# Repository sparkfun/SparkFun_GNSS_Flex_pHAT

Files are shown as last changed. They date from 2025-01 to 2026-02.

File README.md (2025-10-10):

SparkFun GNSS Flex pHAT
========================================

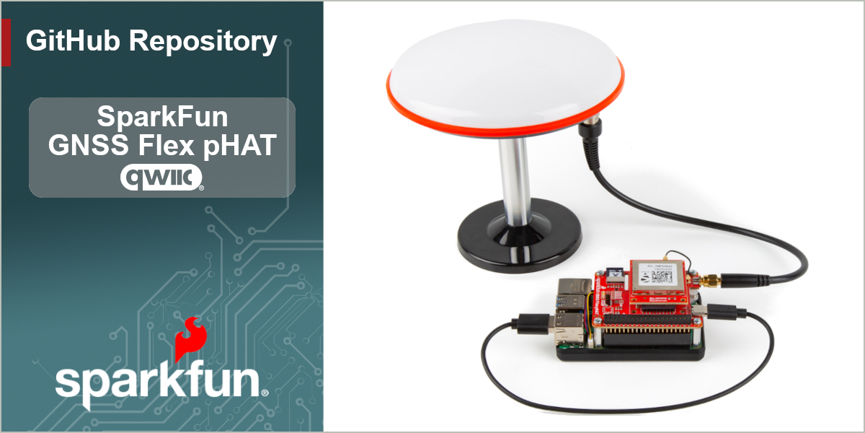
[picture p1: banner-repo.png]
SparkFun GNSS Flex pHAT


[*SparkFun GNSS Flex pHAT (GPS-28137)*](https://www.sparkfun.com/sparkfun-gnss-flex-phat.html)

The [SparkFun GNSS Flex pHAT](https://www.sparkfun.com/sparkfun-gnss-flex-phat.html) is a Raspberry Pi pHAT that functions as a *carrier board* for our SparkPNT GNSS Flex modules. With pre-soldered headers, no soldering is required to stack the pHAT on the headers of a Raspberry Pi, NVIDIA Jetson Nano, Google Coral, or other single-board computer with a similar 40-pin header.

The GNSS Flex pHAT also comes populated with two sets of 2x10 pin, 2mm pitch male headers for attaching a GNSS Flex module. With these headers, the GNSS Flex system is designed to be modular so that boards are pin-compatible for upgrades and can be easily swapped for repairs. Depending on the capabilities of the GNSS Flex module that is connected, these pins will breakout the USB, UART (x4), I<sup>2</sup>C, and SD card interfaces for the GNSS receiver along with any PPS or event signals, using a standardized pin out.

> [!NOTE]
> By default, we use the Raspberry Pi's primary serial bus *(i.e. **TX:** `GPIO14`/Pin `8`; **RX:** `GPIO15`/Pin `9`)* to communicate with the GNSS receiver of the SparkPNT GNSS Flex module. However, users can also utilize any of the other interfaces.

> [!IMPORTANT]
> Depending on the GNSS Flex module, this product will likely require an external antenna:
>
> - Be sure to check out the hookup guide for more information on the GNSS Flex module.
> - Users can also find [GNSS Antennas](https://www.sparkfun.com/gnss/gnss-antennas.html) in our catalog.
>
> Users will have two options for connecting an external GNSS antenna to their GNSS receiver.
>
> - The GNSS Flex modules will usually come with a U.FL connector for external antenna.
> - For a sturdier connection, an SMA connector is available on the SparkFun GNSS Flex pHAT that is bridged to an U.FL connector. Users simply need to jumper the U.FL connectors on both the SparkPNT GNSS Flex module and SparkFun GNSS Flex pHAT with a short U.FL cable.

> [!TIP]
> The SparkFun GNSS Flex pHAT has been tested and verified on the following platforms:
> - [Raspberry Pi](https://www.sparkfun.com/development-boards/single-board-computers/raspberry-pi/raspberry-pi-boards.html): 3B, 3B+, 3A+, Zero 2W, 4B, 5B
> - [NVidia Jetson Orin Nano](https://www.sparkfun.com/nvidia-jetson-orin-nano-developer-kit.html)

Documentation
--------------
- **[Hookup Guide (mkdocs)](http://docs.sparkfun.com/SparkFun_GNSS_Flex_System/)** - A hookup guide for the entire ecosystem of SparkFun GNSS Flex carrier boards and SparkPNT GNSS Flex modules, hosted by GitHub pages.<br>
   

Repository Contents
-------------------
- **[/docs](/docs/)** - Online documentation files
  - [/assets](/docs/assets/) - Assets files
    - [/3d_model](/docs/assets/3d_model/) - Files for the 3D models
      - [/3D CAD Model](/docs/assets/3d_model/cad_model.step) (.step)
    - [/board_files](/docs/assets/board_files/) - Files for the product design
      - [KiCad Design Files](/docs/assets/board_files/kicad_files.zip) (.zip)
      - [Schematic](/docs/assets/board_files/schematic.pdf) (.pdf)
      - [Dimensions](/docs/assets/board_files/dimensions.pdf) (.pdf)
    - [/component_documentation](/docs/assets/component_documentation/) - Datasheets for hardware components
    - [/img/hookup_guide/](/docs/assets/img/hookup_guide/) - Images for hookup guide documentation
- **[/Hardware](/Hardware/)** - Hardware design files (.brd, .sch)
  - **[/Production](/Production/)** - Production files

Product Variants
----------------
GNSS Flex *Carrier* Boards:
- [GPS-28962](https://www.sparkfun.com/sparkfun-gnss-flex-breakout.html) - GNSS Flex Breakout
- [GPS-28137](https://www.sparkfun.com/sparkfun-gnss-flex-phat.html) - GNSS Flex pHAT *(only)*

- GNSS Flex pHAT Kits:
  - pHAT + GNSS Module *(only)*:
    - [GPS-28766](https://www.sparkfun.com/sparkfun-gnss-flex-phat-mosaic-x5.html) - w/ the Septentrio mosaic-X5 GNSS Flex module
    - [GPS-28929](https://www.sparkfun.com/sparkfun-gnss-flex-phat-lg290p.html) - w/ the Quectel LG290P GNSS Flex module
    - [GPS-29491](https://www.sparkfun.com/sparkfun-gnss-flex-phat-dan-f10n.html) - w/ the u-blox DAN-F10N GNSS Flex module
    - [GPS-29887](https://www.sparkfun.com/sparkfun-gnss-flex-phat-zed-x20p.html) - w/ the u-blox ZED-X20P GNSS Flex module
    - [GPS-29890](https://www.sparkfun.com/sparkfun-gnss-flex-phat-lg580p.html) - w/ the Quectel LG580P GNSS Flex module
  - pHAT + GNSS Module w/ IMU:
    - [GPS-29891](https://www.sparkfun.com/sparkfun-gnss-flex-phat-lg290p-im19-imu.html) - w/ the Quectel LG290P GNSS Flex module + IM19 IMU
    - [GPS-29888](https://www.sparkfun.com/sparkfun-gnss-flex-phat-zed-x20p-im19-imu.html) - w/ the u-blox ZED-X20P GNSS Flex module + IM19 IMU

Version History
---------------
- [v01](https://github.com/sparkfun/SparkFun_GNSS_Flex_pHAT/releases/tag/v01) - Initial Release
- [v02](https://github.com/sparkfun/SparkFun_GNSS_Flex_pHAT/releases/tag/v02) - Adds DAN-F10N GNSS Flex module
- [v03](https://github.com/sparkfun/SparkFun_GNSS_Flex_pHAT/releases/tag/v03) - Adds LG290P and ZED-X20P GNSS Flex modules w/ optional IM19 IMU
- [v04](https://github.com/sparkfun/SparkFun_GNSS_Flex_pHAT/releases/tag/v04) - Update docs and link GNSS Flex breakout board
- [v10](https://github.com/sparkfun/SparkFun_GNSS_Flex_pHAT/releases/tag/v10) - Refactored the 3D model for new color adjustment script and linked the LG580P GNSS Flex module

License Information
-------------------

This product is ***open source***!

Please review the [`LICENSE.md`](./LICENSE.md) file for license information.

If you have any questions or concerns about licensing, please contact technical support on our [SparkFun forums](https://forum.sparkfun.com/viewforum.php?f=152).

Distributed as-is; no warranty is given.

- Your friends at SparkFun.

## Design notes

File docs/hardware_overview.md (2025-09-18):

<article style="text-align: center;" markdown>
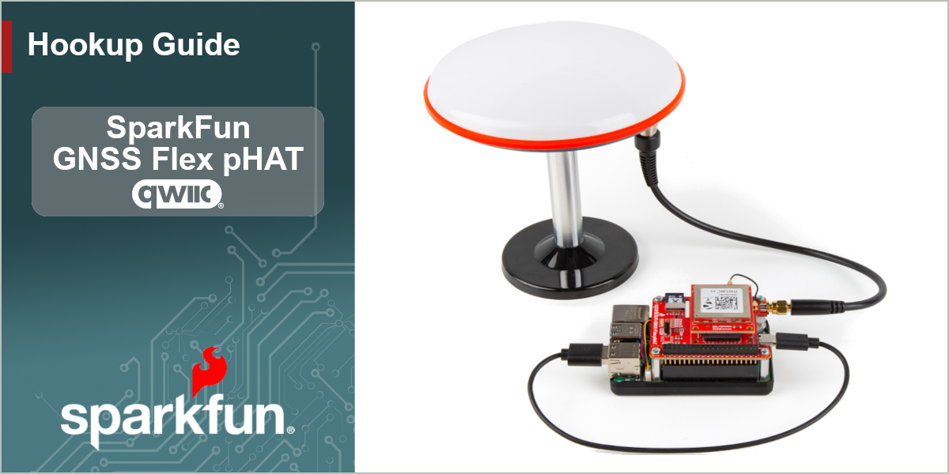
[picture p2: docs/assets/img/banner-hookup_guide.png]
Banner

</article>

!!! info "pHAT (not HAT+)"
	This is product does not completely meet Raspberry Pi's HAT+ specification.

	- An identification EEPROM is not populated on the board; however, we do provide a footprint for future use.
	- Without an ID EEPROM, a Raspberry Pi cannot automatically identify this board. Therefore, users will need to manually [install any software](software_overview.md) and provide configurations for the [hardware connections](#40-pin-gpio-header).

## Introduction

<div class="grid cards desc" markdown>

-   <a href="https://www.sparkfun.com/sparkfun-gnss-flex-phat.html">
	**SparkFun GNSS Flex pHAT**<br>
	**SKU:** GPS-28137

	---

	<figure markdown>
	Product Thumbnail
	</figure></a>

	<article style="text-align: center;" markdown>
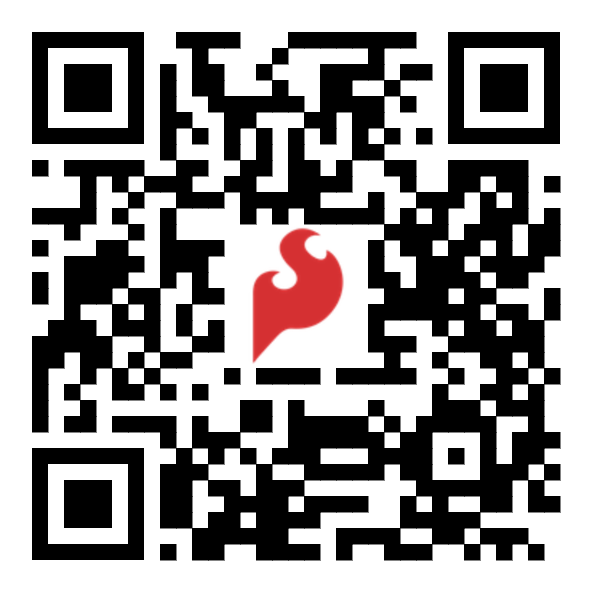
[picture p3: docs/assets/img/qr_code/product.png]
QR code to product page
	
	[Purchase from SparkFun :fontawesome-solid-cart-plus:{ .heart }](https://www.sparkfun.com/sparkfun-gnss-flex-phat.html){ .md-button .md-button--primary }
	</article>

-	The SparkFun GNSS Flex pHAT is a Raspberry Pi pHAT that functions as a [*carrier board*](../carriers.md) for our [SparkPNT GNSS Flex modules](../modules.md). With pre-soldered headers, no soldering is required to stack the pHAT on the headers of a Raspberry Pi, NVIDIA Jetson Nano, Google Coral, or other single-board computer with a similar 40-pin header.

	The GNSS Flex pHAT also comes populated with two sets of 2x10 pin, 2mm pitch male headers for attaching a GNSS Flex module. With these headers, the GNSS Flex system is designed to be modular so that boards are pin-compatible for upgrades and can be easily swapped for repairs. Depending on the capabilities of the GNSS Flex module that is connected, these pins will breakout the USB, UART (x4), I^2^C, and SD card interfaces for the GNSS receiver along with any PPS or event signals, using a standardized pin out.

</div>

## Design Files

<!-- Import the component -->
<script type="module" src="https://ajax.googleapis.com/ajax/libs/model-viewer/3.5.0/model-viewer.min.js"></script>

<div class="grid cards desc" markdown>

-   :kicad-primary:{ .enlarge-logo } **Design Files**

	---

	- :fontawesome-solid-file-pdf: [Schematic](./assets/board_files/schematic.pdf)
	- :material-folder-zip: [KiCad Files](./assets/board_files/kicad_files.zip)
	- :material-rotate-3d: [STEP File](./assets/3d_model/cad_model.step)
	- :fontawesome-solid-file-pdf: [Board Dimensions](./assets/board_files/dimensions.pdf):

	<br>

	**Hardware Included w/ Kit**

	---

	- x1 - [SparkPNT GNSS Flex Module](../modules.md)
	- x1 - [Tall GPIO Female Headers - 2x20 Pin](https://www.sparkfun.com/tall-gpio-female-headers-2x20-pin.html)
	- x1 - [50mm U.FL to U.FL Cable](https://www.sparkfun.com/u-fl-to-u-fl-mini-coax-cable-50mm.html)
	- x4 - Aluminum Hex Standoff
		- Thread: M2.5-0.45; Length: 16mm
	- x8 - Phillips Machine Screw
		- Thread: M2.5-0.45x8mm

-   <!-- Boxes in tabs -->

	=== "3D Model"
		<article style="text-align: center;" markdown>
		<model-viewer src="../assets/3d_model/web_model.glb" camera-controls poster="../assets/3d_model/poster.png" tone-mapping="neutral" shadow-intensity="2" shadow-softness="0.2" camera-orbit="0deg 75deg 0.1623m" field-of-view="25.11deg" style="width: 100%; height: 450px;">
		</model-viewer>
		</article>

		???+ tip "Manipulate 3D Model"
			<article style="text-align: center;" markdown>

			| Controls       | Mouse                    | Touchscreen    |
			| :------------- | :----------------------: | :------------: |
			| Zoom           | Scroll Wheel             | 2-Finger Pinch |
			| Rotate         | ++"Left-Click"++ & Drag  | 1-Finger Drag  |
			| Move/Translate | ++"Right-Click"++ & Drag | 2-Finger Drag  |

			</article>

	=== "Dimensions"
		<article style="text-align: center;" markdown>
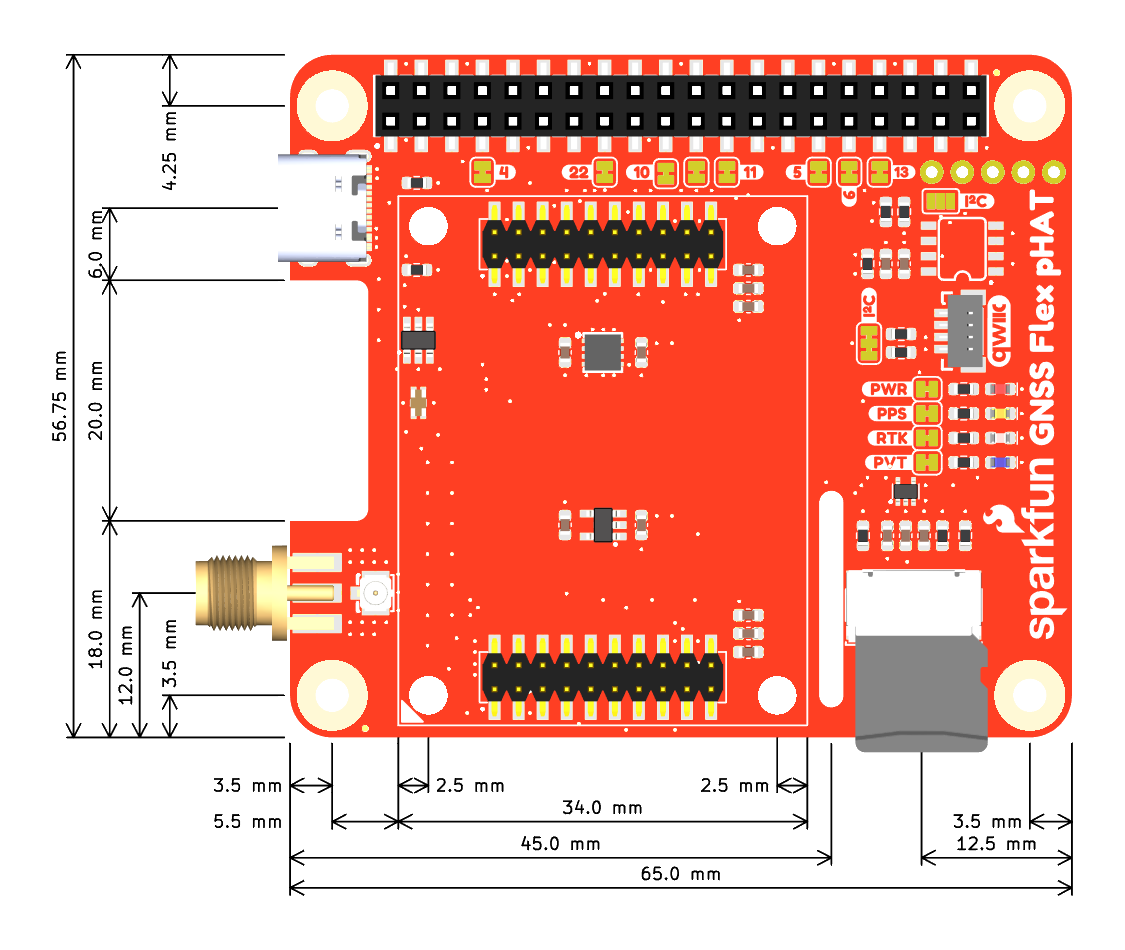
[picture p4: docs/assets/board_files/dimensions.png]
Board Dimensions
		
		<figcaption markdown>Dimensions of the GNSS Flex pHAT.</figcaption>
		</article>

		???+ tip "Need more measurements?"
			For more information about the board's dimensions, users can download the [KiCad files](./assets/board_files/kicad_files.zip) for this board. These files can be opened in KiCad and additional measurements can be made with the measuring tool.

			!!! info ":octicons-download-16:{ .heart } KiCad - Free Download!"
				KiCad is free, open-source [CAD]("computer-aided design") program for electronics. Click on the button below to download their software. *(\*Users can find out more information about KiCad from their [website](https://www.kicad.org/).)*

				<article style="text-align: center;" markdown>
				[Download :kicad-primary:{ .enlarge-logo }](https://www.kicad.org/download/ "Go to downloads page"){ .md-button .md-button--primary }
				</article>

			???+ info ":straight_ruler: Measuring Tool"
				This video demonstrates how to utilize the dimensions tool in KiCad, to include additional measurements:

				<article class="video-500px" style="text-align: center; margin: auto;" markdown>
				<iframe src="https://www.youtube.com/embed/-eXuD8pkCYw" title="KiCad Dimension Tool" frameborder="0" allow="accelerometer; autoplay; clipboard-write; encrypted-media; gyroscope; picture-in-picture" allowfullscreen></iframe>
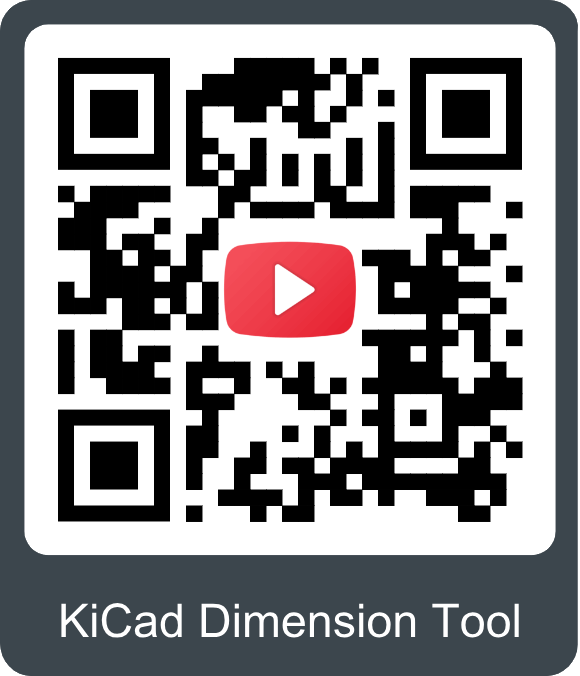
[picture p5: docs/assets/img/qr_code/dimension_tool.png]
QR code to play video
				
				</article>

</div>

## Board Layout
The GNSS Flex system is designed around two 2x10-pin, 2mm pitch headers used mate the two types of boards. A standardized pin layout, keeps the ecosystem pin-compatible for upgrades and allows board to be easily swapped for repairs. Depending on the capabilities of the GNSS receiver, these pins will breakout the USB, UART (x4), I^2^C, and SD card interfaces along with any PPS or event signals of the GNSS receiver.

<figure markdown>
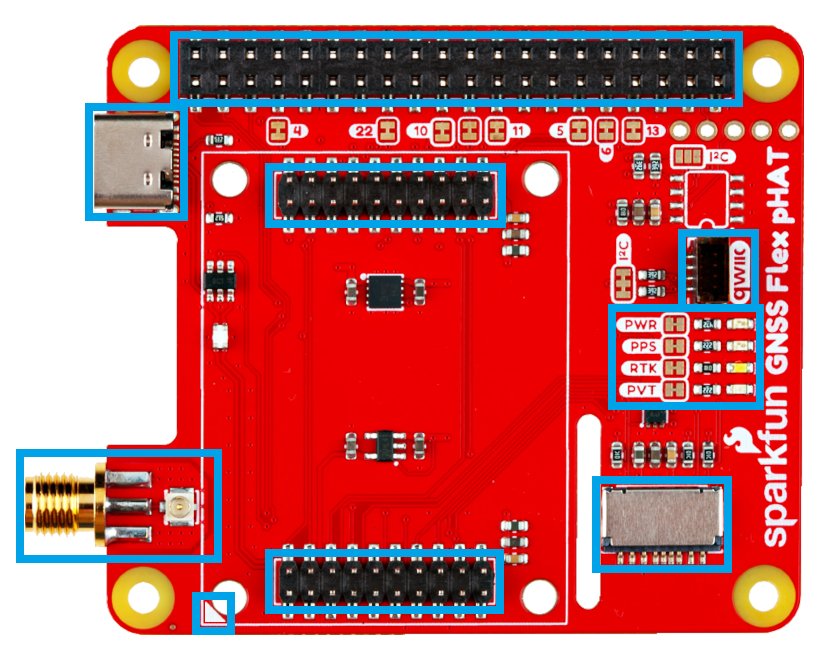
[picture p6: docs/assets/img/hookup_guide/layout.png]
Board Layout

<figcaption markdown>Layout of the major components of the GNSS Flex pHAT.</figcaption>
</figure>

The GNSS Flex pHAT has the following features:

1. **40-pin GPIO Header**
:	The 2x20 pin, 0.1" pitch female header for stacking the pHAT on top the Raspberry Pi's 40-pin GPIO header.
1. **GNSS Flex Headers**
:	Two sets of 2x10 pin, 2mm pitch female headers for connecting a GNSS Flex module.
1. **Alignment Indicator**
: Used to indicate the board alignment of a GNSS Flex module.
1. **Antenna Bridge**
:	U.FL and SMA connectors for attaching an external GNSS antenna.
1. **Status LEDs**
: Four status indication LEDs for the pHAT and attached GNSS Flex module.
1. **USB-C Connector**
:	A USB connector that breaks out the USB interface of an attached GNSS Flex module.
1. **SD Card Slot**
: Depending on the capabilities of the GNSS Flex module, a &micro;SD card slot for data logging.
1. **Qwiic Connector**
: A Qwiic connector for attaching peripheral devices to the I^2^C bus.

## Antenna Bridge
The SMA connector provides users with a more robust interface for attaching an external GNSS antenna. With the U.FL and SMA connectors bridged together and their ground plane isolated from the rest of the board, this allows users to pass the antenna connection from the GNSS Flex module to the GNSS Flex pHAT.

<figure markdown>
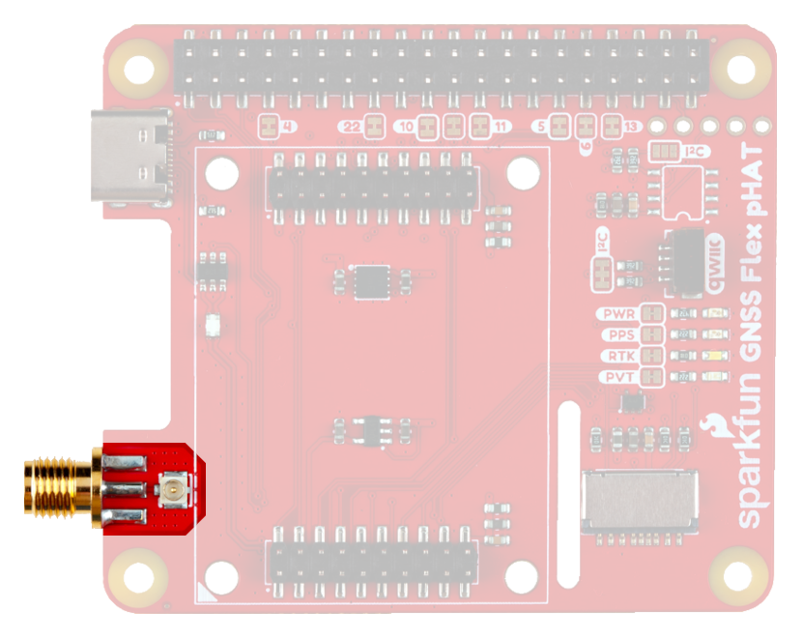
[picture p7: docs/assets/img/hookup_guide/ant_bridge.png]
Antenna bridge

<figcaption markdown>An SMA antenna bridge on the GNSS Flex pHAT, which provides a more robust connection.</figcaption>
</figure>

## 40-pin GPIO Header
In its simplest form, the SparkFun GNSS Flex pHAT sits atop a Raspberry Pi interfacing with its 40-pin header.

<figure markdown>
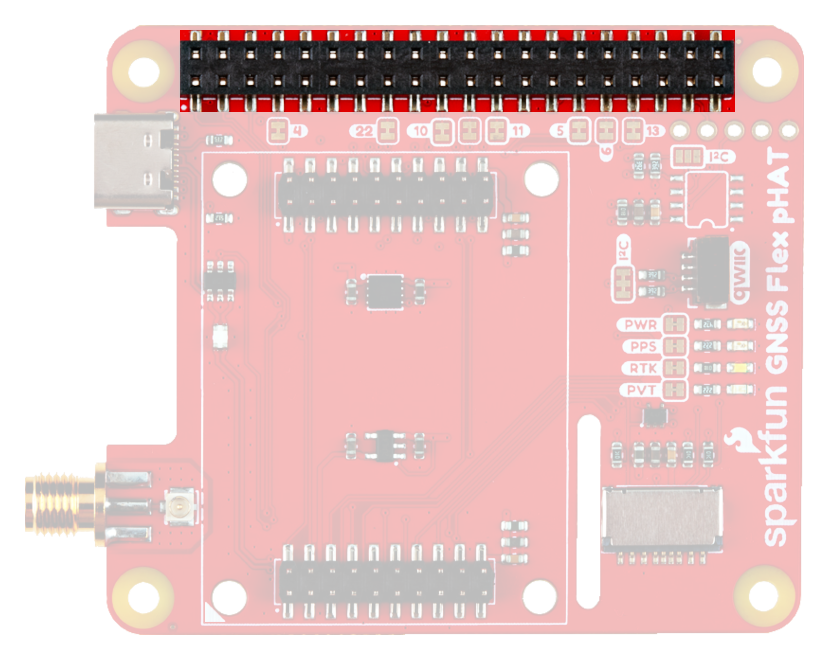
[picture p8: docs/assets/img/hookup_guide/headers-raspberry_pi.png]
GPIO header

<figcaption markdown>The 40-pin female GPIO header for attaching to an SBC.</figcaption>
</figure>

### Interfaces
The following interfaces and signals of the GNSS Flex system are connected to the 40-pin female GPIO header of the GNSS Flex pHAT. Below, are tables detailing the pin connections for each interface.

!!! tip "UART Numbering"
	Please note that the UART numbers (UART1 - UART4) listed below follow the GNSS Flex Module UART numbering scheme. The mosaic-X5 supports four hardware UARTs (COM1 - COM4). The LG290P supports only three (UART1 - UART3).

	Please also note that the UART numbers on Raspberry Pi will be different, as will the `/dev/ttyAMA` device names. There is not a 1:1 mapping between the GNSS Flex UART numbers and the Raspberry Pi UART numbers. The Raspberry Pi UART numbers also vary from model to model; the Pi 5 and Pi 4 numbering is different for example.

=== "UART"

	<div class="grid cards desc" markdown>

	<div markdown>

	=== "UART1"
		<article style="text-align: center;" markdown>

		| GNSS Flex Pin | Raspberry Pi GPIO |
		| :---: | :---------------- |
		| `RX1` | `GPIO14` *(`TX`)* |
		| `TX1` | `GPIO15` *(`RX`)* |

		*Highlighted in Green*

		</article>

	=== "UART2"
		<article style="text-align: center;" markdown>

		| GNSS Flex Pin | Raspberry Pi GPIO |
		| :----: | :------------------- |
		| `RX2`  | `GPIO08` *(`CE0`)*   |
		| `TX2`  | `GPIO09` *(`POCI0`)* |
		| `RTS2` | `GPIO10` *(`PICO0`)* |
		| `CTS2` | `GPIO11` *(`SLK0`)*  |

		*Highlighted in Blue*

		</article>

	=== "UART3"
		<article style="text-align: center;" markdown>

		| GNSS Flex Pin | Raspberry Pi GPIO |
		| :----: | :------------------- |
		| `RX3`  | `GPIO04` *(`GCLK0`)* |
		| `TX3`  | `GPIO05` *(`GCLK1`)* |
		| `RTS3` | `GPIO06` *(`GCLK2`)* |
		| `CTS3` | `GPIO07` *(`CE1`)*   |

		*Highlighted in Yellow*

		</article>

	=== "UART4"
		<article style="text-align: center;" markdown>

		| GNSS Flex Pin | Raspberry Pi GPIO |
		| :---: | :------------------ |
		| `RX4` | `GPIO12` *(`PMW0`)* |
		| `TX4` | `GPIO13` *(`PMW1`)* |

		*Highlighted in Red*

		</article>

	</div>

	<div markdown>

	<figure markdown>
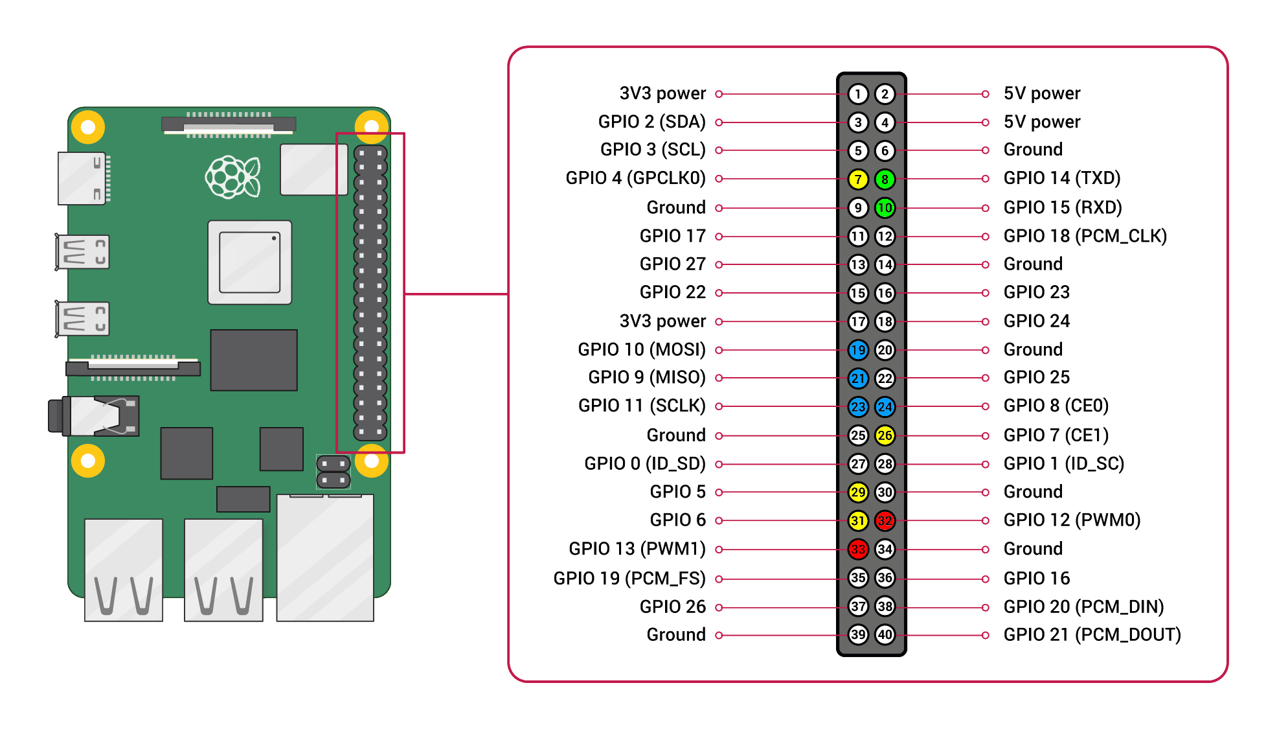
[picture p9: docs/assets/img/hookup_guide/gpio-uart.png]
GPIO header
	
	<figcaption markdown>The pin connections of the UART interface, from the GNSS Flex system to the 40-pin female GPIO header.</figcaption>
	</figure>

	</div>

	</div>

=== "I^2^C"

	<div class="grid cards desc" markdown>

	<div markdown>

	<article style="text-align: center;" markdown>

	| GNSS Flex Pin | Raspberry Pi GPIO |
	| :---: | :------------------ |
	| `SDA` | `GPIO02` *(`SDA`)* |
	| `SCL` | `GPIO03` *(`SCL`)* |

	</article>

	</div>

	<div markdown>

	<figure markdown>
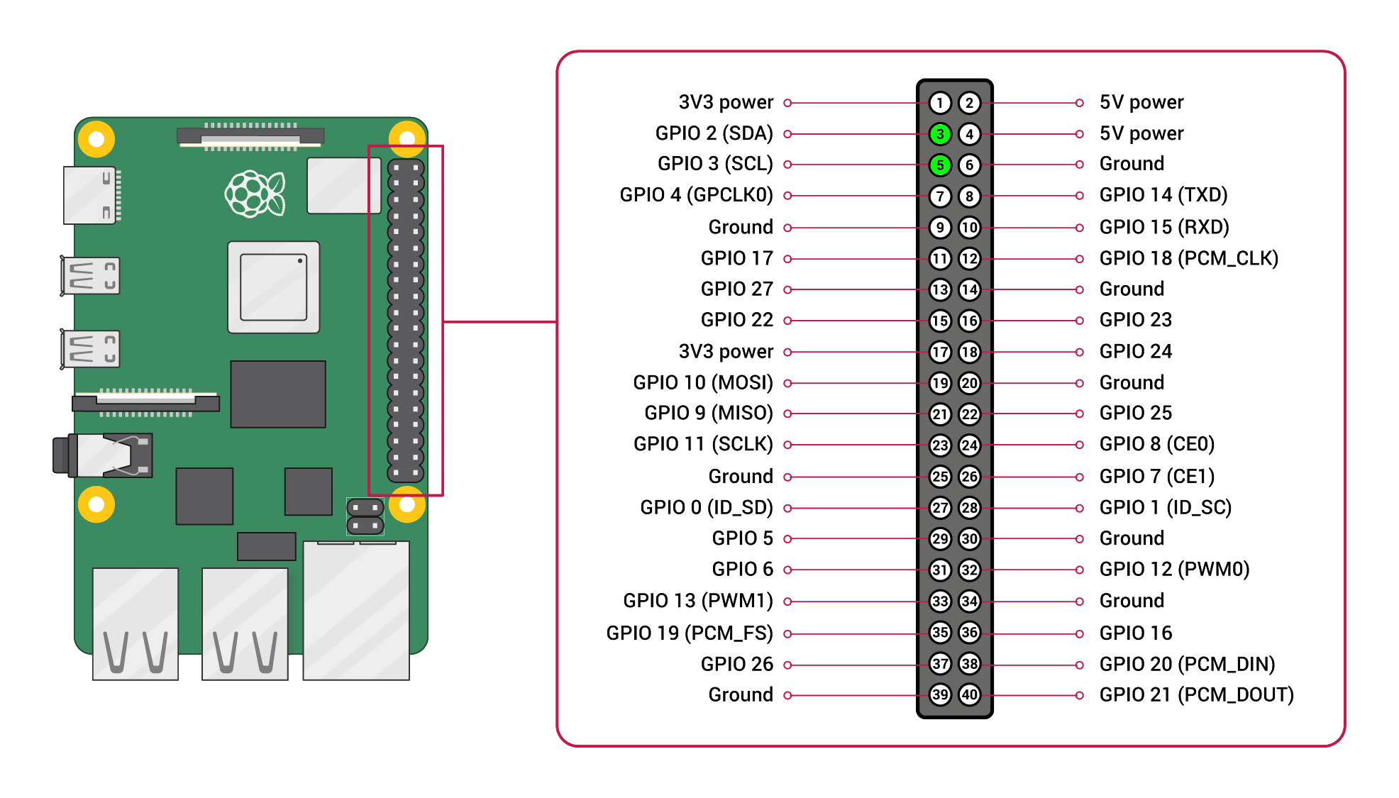
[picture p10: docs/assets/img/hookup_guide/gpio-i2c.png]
GPIO header
	
	<figcaption markdown>The pin connections of the I^2^C interface, from the GNSS Flex system to the 40-pin female GPIO header.</figcaption>
	</figure>

	</div>

	</div>

=== "PPS"

	<div class="grid cards desc" markdown>

	<div markdown>

	<article style="text-align: center;" markdown>

	| GNSS Flex Pin | Raspberry Pi GPIO |
	| :----: | :------- |
	| `PPS1` | `GPIO22` |
	| `PPS2` | `GPIO23` |

	</article>

	</div>

	<div markdown>

	<figure markdown>
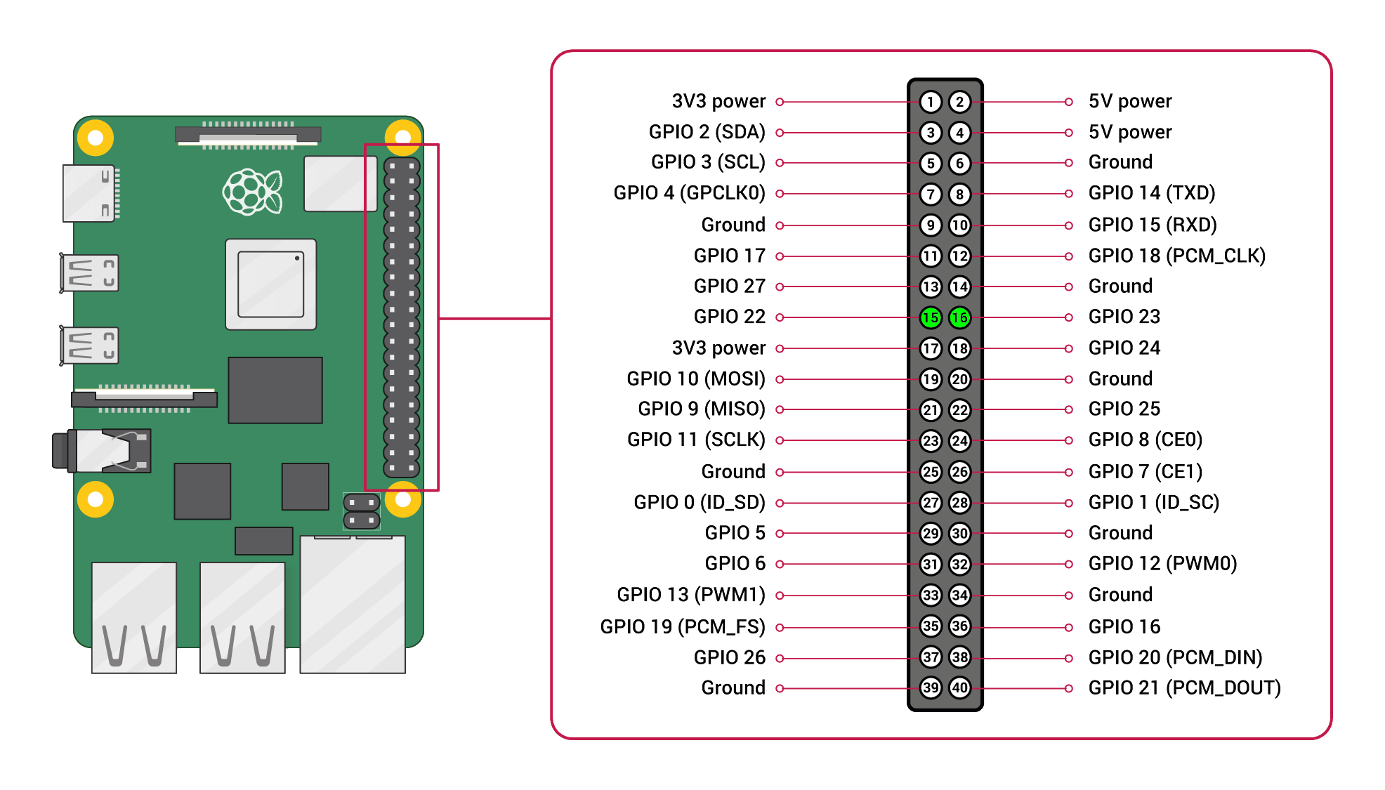
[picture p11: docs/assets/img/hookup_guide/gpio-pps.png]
GPIO header
	
	<figcaption markdown>The pin connections of the PPS signals, from the GNSS Flex system to the 40-pin female GPIO header.</figcaption>
	</figure>

	</div>

	</div>

=== "Event"

	<div class="grid cards desc" markdown>

	<div markdown>

	<article style="text-align: center;" markdown>

	| GNSS Flex Pin | Raspberry Pi GPIO |
	| :------: | :------- |
	| `EVENTA` | `GPIO24` |
	| `EVENTB` | `GPIO25` |

	</article>

	</div>

	<div markdown>

	<figure markdown>
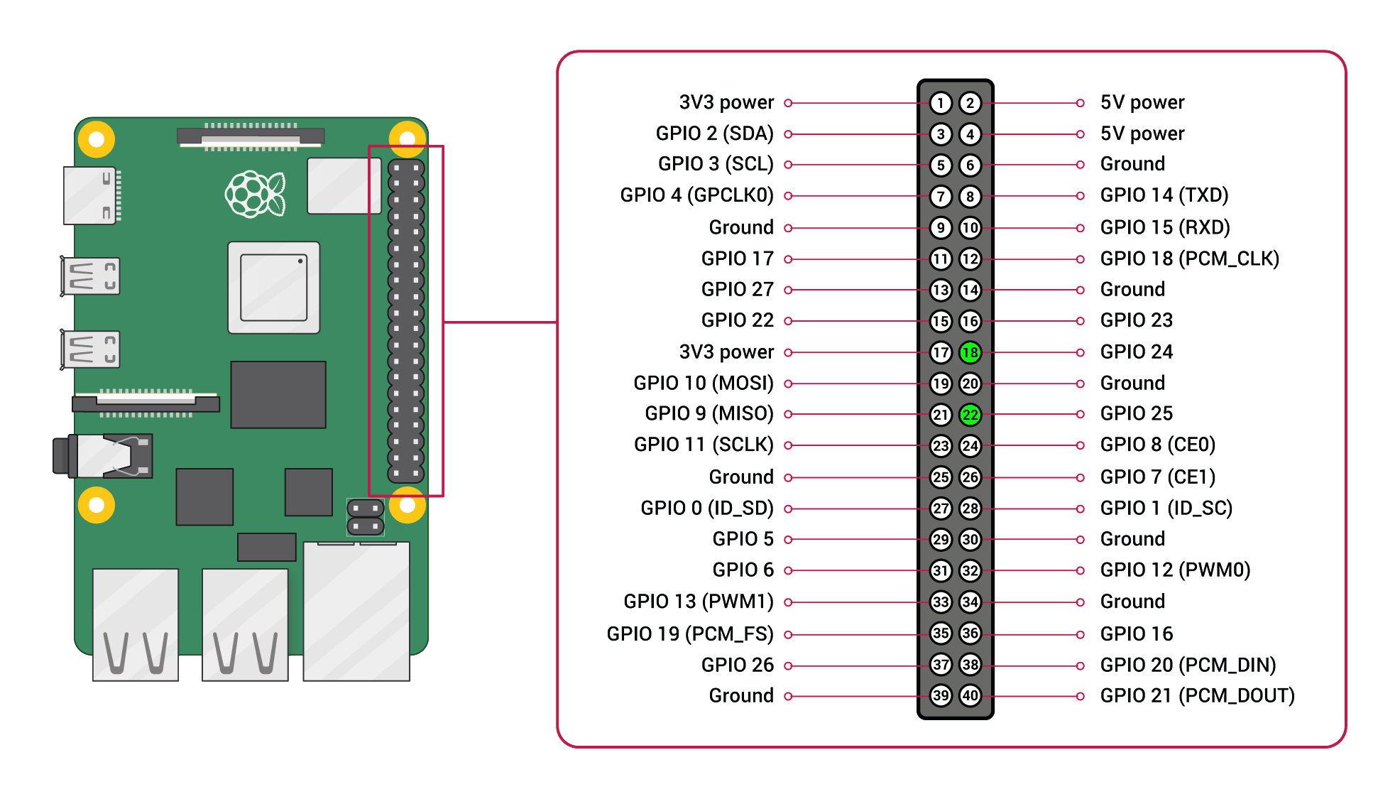
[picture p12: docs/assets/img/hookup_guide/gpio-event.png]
GPIO header
	
	<figcaption markdown>The pin connections of the event triggers, from the GNSS Flex system to the 40-pin female GPIO header.</figcaption>
	</figure>

	</div>

	</div>

## LEDs
There are four status LEDs on the GNSS Flex pHAT:

<div class="grid" markdown>

<div markdown>

<figure markdown>
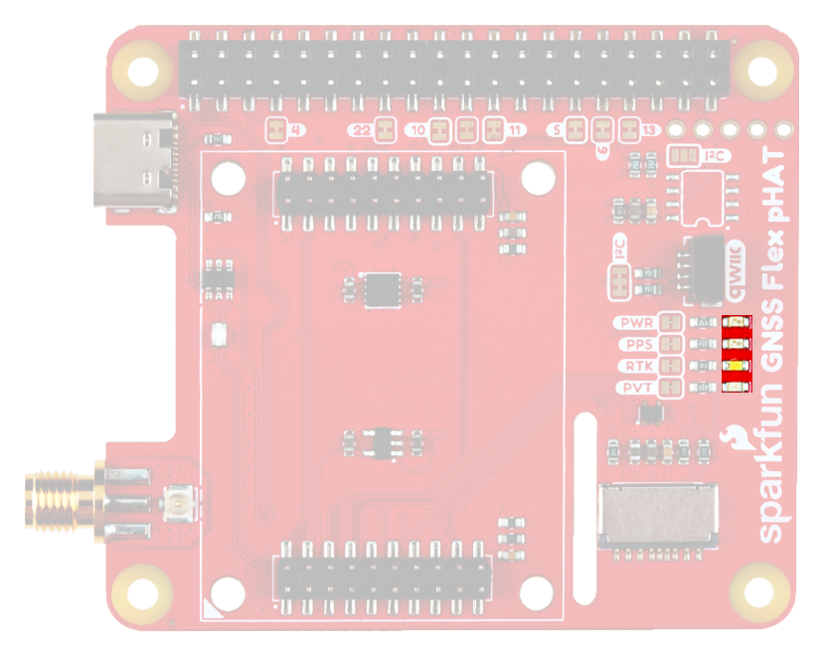
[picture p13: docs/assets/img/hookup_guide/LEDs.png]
Status LEDs

<figcaption markdown>The status LED indicators on the GNSS Flex pHAT.</figcaption>
</figure>

</div>

<div markdown>

- `PWR` - Power *(Red)*
	- Turns on once power is supplied to the board from the 40-pin GPIO header
- `PPS` - Pulse-Per-Second *(Yellow)*
	- Indicates when there is a pulse-per-second signal from the GNSS Flex module
- `RTK` - RTK *(White)*
	- Usually indicates when an RTK fix has been established or when the correct RTCM data is being received by the GNSS Flex module
- `PVT` - PVT *(Blue)*
	- Usually, indicates when an GNSS lock or a position fix has been established by the GNSS Flex module

</div>

</div>

## USB Connector
Depending on the capabilities of the GNSS receiver, the USB connector breaks out the USB interface from the GNSS Flex module.

<figure markdown>
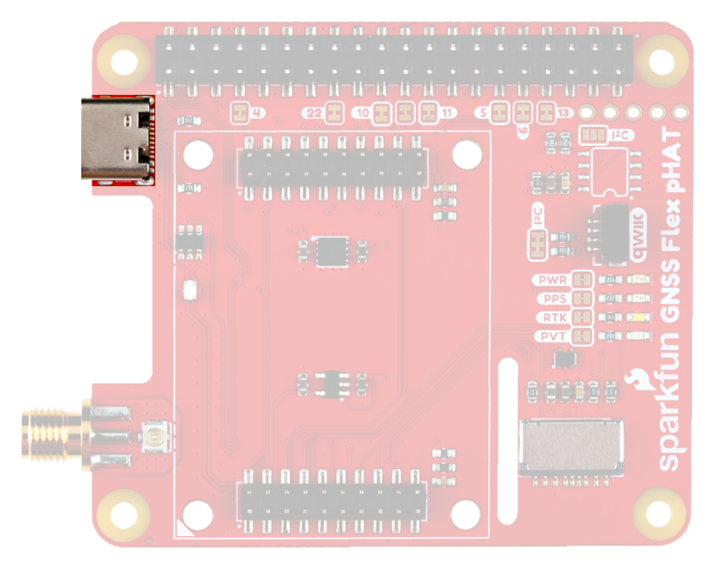
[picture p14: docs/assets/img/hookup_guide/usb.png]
USB connector

<figcaption markdown>The USB connector on the GNSS Flex pHAT.</figcaption>
</figure>

## SD Card Slot
Depending on the capabilities of the GNSS receiver, the &micro;SD card slot can be used for data logging.

<figure markdown>
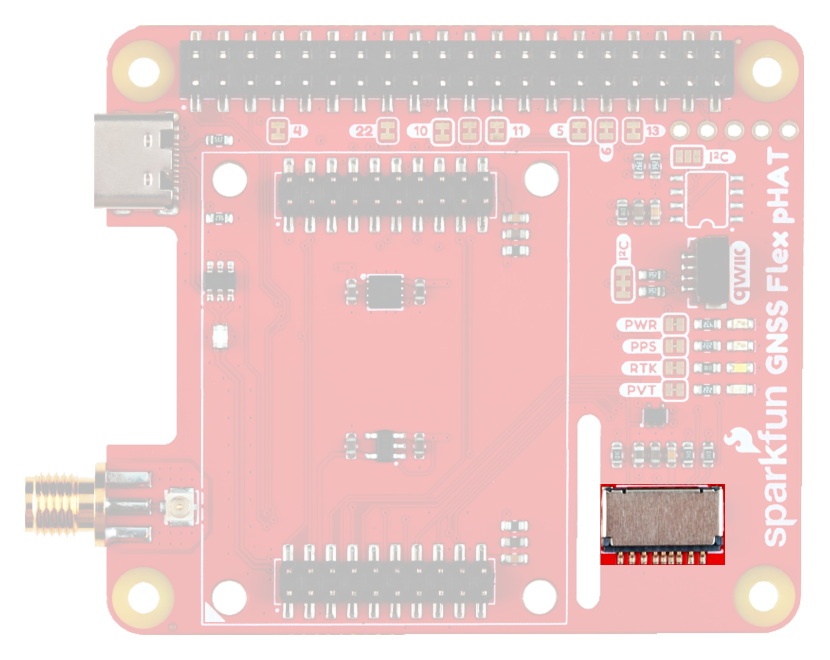
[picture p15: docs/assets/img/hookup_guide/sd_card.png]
SD card slot

<figcaption markdown>The SD card slot on the GNSS Flex pHAT.</figcaption>
</figure>

## Qwiic Connector
The Qwiic connector attached to the primary I^2^C interface of the 40-pin GPIO header.

<figure markdown>
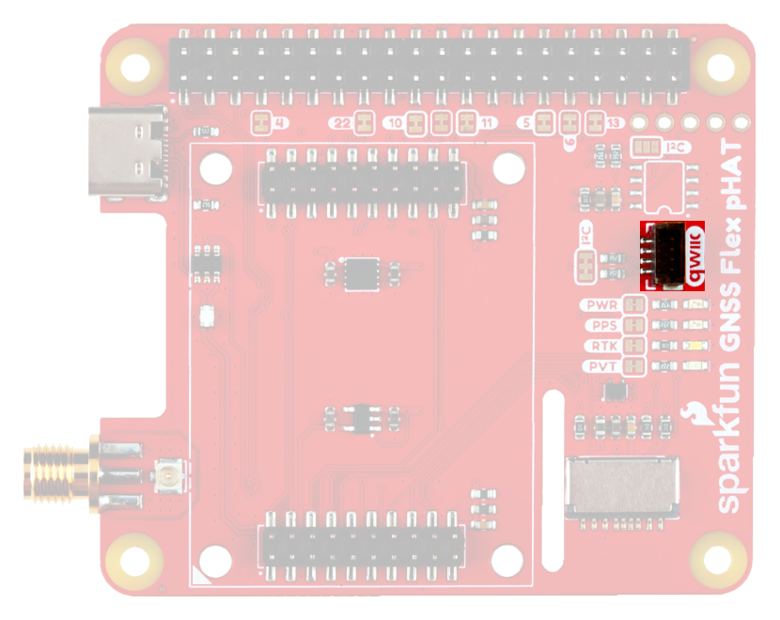
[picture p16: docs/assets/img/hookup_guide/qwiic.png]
Qwiic connector

<figcaption markdown>The Qwiic connector on the GNSS Flex pHAT.</figcaption>
</figure>

??? tip "What is Qwiic?"

	<div class="grid" markdown>

	<div markdown>

	<!-- Qwiic Banner -->
	<article style="text-align: center;" markdown>
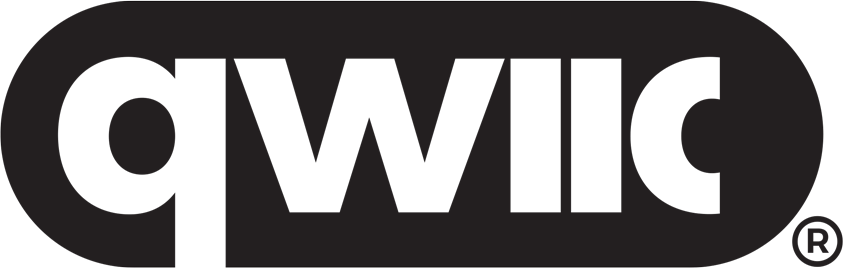
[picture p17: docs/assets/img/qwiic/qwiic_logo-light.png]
Qwiic Logo - light theme (https://www.sparkfun.com/qwiic)
	
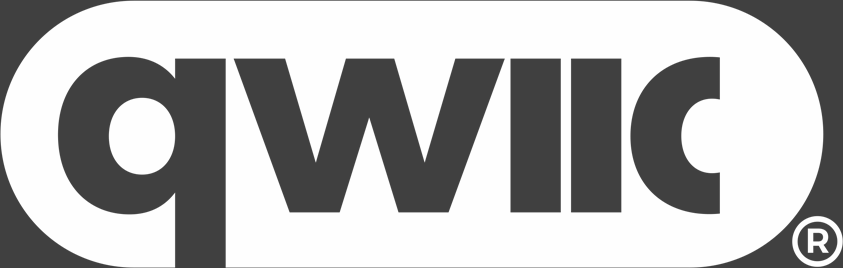
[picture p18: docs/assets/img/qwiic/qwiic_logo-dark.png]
Qwiic Logo - dark theme (https://www.sparkfun.com/qwiic)
	
	</article>

	---

	The [Qwiic connect system](https://www.sparkfun.com/qwiic) is a solderless, polarized connection system that allows users to seamlessly daisy chain I^2^C boards together. Play the video, to learn more about the Qwiic connect system or click on the banner above to learn more about [Qwiic products](https://www.sparkfun.com/qwiic).

	</div>

	<div style="max-height=400px;" markdown>

	<article class="video-500px" style="text-align: center; margin: auto;" markdown>
	<iframe src="https://www.youtube.com/embed/x0RDEHqFIF8" title="SparkFun's Qwiic Connect System" frameborder="0" allow="accelerometer; encrypted-media; gyroscope; picture-in-picture" allowfullscreen></iframe>
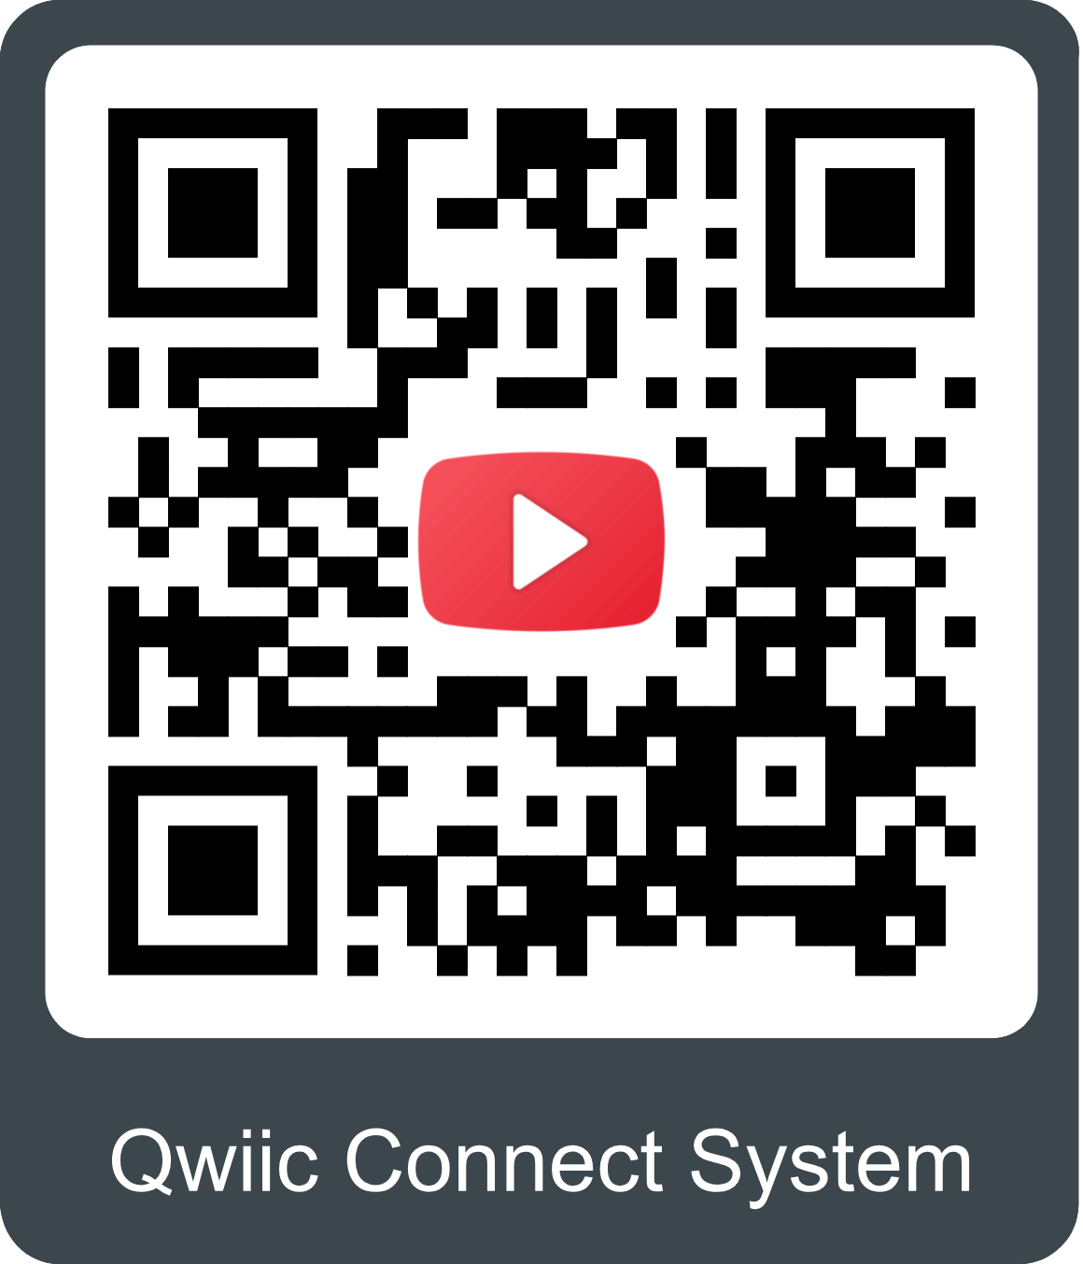
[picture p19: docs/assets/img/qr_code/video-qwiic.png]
QR code to instructional video
	
	</article>

	</div>

	</div>

	!!! info "Features of the Qwiic System"

		=== "No Soldering"

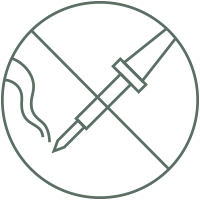
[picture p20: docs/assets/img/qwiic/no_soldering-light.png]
no soldering - light theme
			
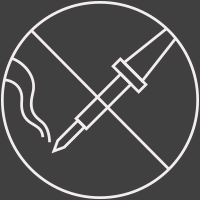
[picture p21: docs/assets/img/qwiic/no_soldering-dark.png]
no soldering - dark theme
			

			Qwiic cables (4-pin JST) plug easily from development boards to sensors, shields, accessory boards and more, making easy work of setting up a new prototype.

		=== "Polarized Connector"

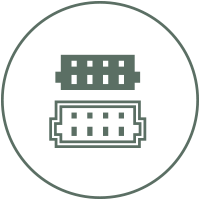
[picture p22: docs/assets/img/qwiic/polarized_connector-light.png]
polarized connector - light theme
			
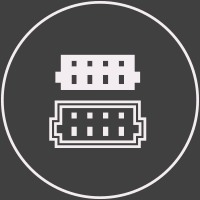
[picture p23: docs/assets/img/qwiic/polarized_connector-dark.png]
polarized connector - dark theme
			

			There's no need to worry about accidentally swapping the `SDA` and `SCL` wires on your breadboard. The Qwiic connector is polarized so you know you’ll have it wired correctly every time.

			The part numbers for the PCB connector is `SM04B-SRSS` ([Datasheet](https://cdn.sparkfun.com/assets/parts/1/2/2/8/9/Qwiic_Connector_Datasheet.pdf)) and the mating connector on the cables is `SHR04V-S-B`; or an equivalent *1mm pitch, 4-pin JST connection*.

		=== "Daisy Chain-able"

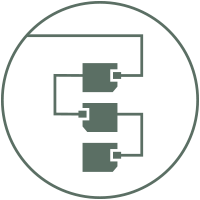
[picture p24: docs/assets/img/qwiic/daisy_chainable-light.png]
daisy chainable - light theme
			
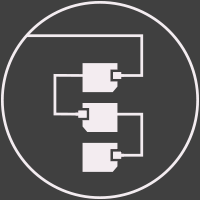
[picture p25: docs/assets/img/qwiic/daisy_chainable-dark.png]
daisy chainable - dark theme
			

			It’s time to leverage the power of the I^2^C bus! Most Qwiic boards will have two or more connectors on them, allowing multiple devices to be connected.

## Jumpers
There are twenty-three jumpers on the GNSS Flex pHAT:

<div class="grid" markdown>

<div markdown>

<figure markdown>
Jumpers on the top of the pHAT
<figcaption markdown>Jumpers on the top of the GNSS Flex pHAT.</figcaption>
</figure>

</div>

<div markdown>

<figure markdown>
Jumpers on the bottoms of the pHAT
<figcaption markdown>Jumpers on the bottom of the GNSS Flex pHAT.</figcaption>
</figure>

</div>

</div>

- The `SHLD` jumper can be cut to isolate the shielding of the USB-C connector from the ground plane of the board.
- All the jumpers labeled with numbers, can be cut tp disconnect a signal from the GNSS Flex header to the associated Raspberry Pi GPIO pin *(refer to the [40-pin GPIO Header section](#40-pin-gpio-header))*.
- All the jumpers next to the status LEDs, can be cut to disable the associated LED.
- There are two `I2C` jumpers; one next to the Qwiic connector and one next to the unpopulated EEPROM footprint.
	- The `I2C` jumper next to the Qwiic connector, can be cut to disconnect the two 3.9k&ohm; pull-up resistors for that I^2^C bus.
	- The `I2C` jumper next to the EEPROM footprint, can be closed to connect two 3.9k&ohm; pull-up resistors if an EEPROM is populated.

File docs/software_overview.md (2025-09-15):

!!! warning "Warning - Resource Requirements"
	When choosing a SBC, please be aware of any resource requirements.

	For example, the mosaic-X GNSS Flex module provides an internal web server, which can be utilized to change its configuration settings. On platforms such as the Raspberry Pi, using the latest Raspberry Pi OS *(Bookworm, at the time of writing)*, the Chromium web browser requires a good amount of RAM to run smoothly. Therefore, some of the older Raspberry Pi models become extremely sluggish to work with.

## Supported Platforms
There are dozens of single board computers (SBCs) to choose from; we have tested this hardware with the Raspberry Pi and Nvidia platforms using their latest OS distributions *(Bookworm and JetPack 6.2)*. To use the SparkFun GNSS Flex pHAT on other platforms, the SBC must have a compatible 40-pin GPIO header that follows Raspberry Pi's standardized pin layout.

???+ tip "Tip - Hardware Recommendations"
	We highly recommend using the Raspberry Pi 4B/5 and latest Nvidia Jetson Orin Nano. While users are free to use other boards or platforms, we cannot guarantee the functionality of our recommended software for those instances.

	- **Jetson Orin Nano (super)** - Tested and verified
	- **Jetson Nano (4GB)** - Tested and verified
	- **Pi 5** - Tested and verified with 4GB version
	- **Pi 4B** - Tested and verified with 2GB and 4GB versions; would recommend avoiding the 1GB version due to the web browser requirements
	- **Pi Zero 2W** - Tested and verified; would recommend avoiding due to the web browser requirements
	- **Pi 3A+** - Tested and verified; would recommend avoiding due to the web browser requirements
	- **Pi 3B+** - Tested and verified
	- **Pi 3B** - Tested and verified; would recommend avoiding due to limitations in processing power
	- **Pi Zero/Zero W** - Avoid

	---

	**PyGPSClient**

	The `PyGPSClient` software that we recommend below, provides a nice graphical user interface for the GNSS Flex modules. However, as with any GUI, it requires a decent amount of computational resources to run smoothly.

	- Users can try using the **Pi Zero 2W**, but just be aware that we noticed a small degree of lag in the GUI.
	- Just avoid using the **Pi 3B** (or older) and **Pi Zero/Zero W** models.

	**mosaic-X5 Web Server**

	The mosaic-X GNSS Flex module provides an internal web server, which can be utilized to change its configuration settings. However, when using the latest Raspberry Pi OS *(Bookworm)*, the Chromium browser requires a decent amount of RAM to function. For this reason, we recommend using any Pi 4B or later model, with **at least 2GB of RAM**.

	Save yourself the trouble and just avoid using the following Raspberry Pi boards:

	- Users can try using the **Pi 3B+** model, but it will require a significant amount of patience waiting for a web page to load. The web page needs to reload each time users change a setting; and again, to save the settings.
	- Just avoid using the **Pi 3B/A+** (or older) and **Pi Zero/Zero W/Zero 2W** models

## Getting Started with your SBC
For users unfamiliar with the following platforms, we have linked additional resources below:

<div class="grid cards" markdown>

- ### Raspberry Pi OS

	---

	- [Raspberry Pi Imager](https://www.raspberrypi.com/software/)
	- [Operating System Images](https://www.raspberrypi.com/software/operating-systems/)
	- [Raspberry Pi Documentation](https://www.raspberrypi.com/documentation/)
		- [Getting Started](https://www.raspberrypi.com/documentation/computers/getting-started.html)
			<article class="video-500px" style="text-align: center; margin: auto;" markdown>
			QR code to play video
			<iframe src="https://www.youtube.com/embed/CQtliTJ41ZE" title="How to set up a Raspberry Pi" frameborder="0" allow="accelerometer; autoplay; clipboard-write; encrypted-media; gyroscope; picture-in-picture" allowfullscreen></iframe>
			</article>
		- [Raspberry Pi OS](https://www.raspberrypi.com/documentation/computers/os.html#updating-and-upgrading-raspberry-pi-os)
		- [Configurations](https://www.raspberrypi.com/documentation/computers/configuration.html)

- ### Nvidia JetPack SDK

	---

	- [JetPack SDK](https://developer.nvidia.com/embedded/jetpack)
		- [NVIDIA SDK Manager Documentation](https://docs.nvidia.com/sdk-manager/)
	- [Getting Started with Jetson Developer Kits](https://developer.nvidia.com/embedded/learn/getting-started-jetson)
		- Jetson Orin Nano Super Developer Kit
			- [User Guide](https://developer.nvidia.com/embedded/learn/jetson-orin-nano-devkit-user-guide/index.html)
			- [Getting Started Guide](https://developer.nvidia.com/embedded/learn/get-started-jetson-orin-nano-devkit)
		- Jetson AGX Orin Developer Kit
			- [User Guide](https://developer.nvidia.com/embedded/learn/jetson-agx-orin-devkit-user-guide/index.html)
			- [Getting Started Guide](https://developer.nvidia.com/embedded/learn/get-started-jetson-agx-orin-devkit)
	- Support
		- [Jetson FAQ](https://developer.nvidia.com/embedded/faq)
		- [Jetson Linux Developer Guide](https://docs.nvidia.com/jetson/l4t/index.html)
		- [Jetson Community Resources](https://developer.nvidia.com/embedded/community/resources)
		- [Jetson Projects Forum](https://forums.developer.nvidia.com/c/agx-autonomous-machines/jetson-embedded-systems/jetson-projects)

</div>

## Update Software
Once users have got their SBC up and running, ensure that it is utilizing the latest software. Run the following commands to update and upgrade any installed packages:

```shell
sudo apt update
sudo apt full-upgrade
sudo apt autoremove --purge && sudo apt clean
```

!!! info
	[Advanced Package Tool (APT)](https://en.wikipedia.org/wiki/APT_(software)) is the recommended way to install, update, and remove software in Raspberry Pi OS. Users can access APT through the `apt` CLI.

## Enable Serial Interface
Depending on the SBC platform, users may need to enable access to the serial interface from the 40-pin GPIO header for the operating system.

### Configuration Settings
In the Raspberry Pi OS, users can enable access to the serial interface through the [`raspi-config`](https://www.raspberrypi.com/documentation/computers/configuration.html#raspi-config) configuration tool. The tool can be utilized through either the CLI or [desktop GUI](https://www.raspberrypi.com/documentation/computers/configuration.html#raspberry-pi-configuration). To change the configuration settings, users will need to navigate through the [Interface options](https://www.raspberrypi.com/documentation/computers/configuration.html#interfacing-options) > [Serial port](https://www.raspberrypi.com/documentation/computers/configuration.html#serial) menus and enable the serial port.

???+ note
	Not all of the advanced configuration options from the CLI are available in the Raspberry Pi Configuration GUI.

!!! tip "Disabling the Linux Serial Console"
	On the Pi 3/4/5/Zero 2W, users should keep [access to the shell disabled from the serial interface](https://www.raspberrypi.com/documentation/computers/configuration.html#disabling-the-linux-serial-console).

!!! tip "Is PyGPSClient disconnecting?"
	If PyGPSClient disconnects from the serial port after a few seconds, you probably still have the Login Shell enabled. Use `raspi-config` to ensure: the serial port hardware is enabled; and that [the login shell is *not* accessible](https://www.raspberrypi.com/documentation/computers/configuration.html#disabling-the-linux-serial-console).

### Additional UARTs
The GNSS Flex pHAT supports up to four hardware UART connections. On Raspberry Pi, it may be necessary to enable the three additional UARTs manually. On Raspberry Pi 5, the additional ports usually appear as `/dev/ttyAMA2`, `/dev/ttyAMA3` and `/dev/ttyAMA4`. In a Terminal Window, type `ls /dev/tty*` to list all the available ports. If the ports are not enabled, you can enable them by editing `/boot/firmware/config.txt`:

- Edit `/boot/firmware/config.txt`

	```shell
	sudo nano /boot/firmware/config.txt
	```

- Add these three lines to the end of the file

	```shell
	dtoverlay=uart2
	dtoverlay=uart3
	dtoverlay=uart4
	```

	!!! rpi
		On the Raspberry Pi 5, we used the following configuration:

		```shell
		# Enable UART Ports
		dtparam=uart0=on
		enable_uart=1

		dtoverlay=uart0
		dtoverlay=uart2,ctsrts
		dtoverlay=uart3,ctsrts
		dtoverlay=uart4
		```

- Save the file using `crtl-X` and select `Save`

- Reboot the Pi with `sudo reboot`

!!! tip "UART Numbering"
	Please note that the UART numbers (UART1 - UART4) listed in the GNSS Flex Module hardware documentation refer to the GNSS UART numbering scheme. The mosaic-X5 supports four hardware UARTs (COM1 - COM4). The LG290P supports only three (UART1 - UART3).

	Please also note that the UART numbers on Raspberry Pi will be different, as will the `/dev/ttyAMA` device names. There is not a 1:1 mapping between the Flex UART numbers and the Raspberry Pi UART numbers. The Raspberry Pi UART numbers also vary from model to model; the Pi 5 and Pi 4 numbering is different for example. On Pi 4, it is necessary to enable UART3 - UART5.

### User Privileges
To access the serial port on most Linux platforms, users will need to be a member of the `tty` and/or `dialout` groups. This can be configured with either the `adduser` or `usermod` utilities.

- [`adduser` Utility](https://manpages.ubuntu.com/manpages/xenial/man8/adduser.8.html)

	```shell
	sudo adduser <username> <groupname>
	```

- [`usermod` Utility](https://manpages.ubuntu.com/manpages/xenial/man8/usermod.8.html)

	```shell
	sudo usermod -aG <groupname> <username>
	```

## Enable I^2^C Interface
Depending on the SBC platform, users may need to enable access to the I^2^C interface from the 40-pin GPIO header for the operating system.

### Configuration Settings
In the Raspberry Pi OS, users can enable access to the serial interface through the [`raspi-config`](https://www.raspberrypi.com/documentation/computers/configuration.html#raspi-config) configuration tool. The tool can be utilized through either the CLI or [desktop GUI](https://www.raspberrypi.com/documentation/computers/configuration.html#raspberry-pi-configuration). To change the configuration settings, users will need to navigate through the [Interface options](https://www.raspberrypi.com/documentation/computers/configuration.html#interfacing-options) > [I2C port](https://www.raspberrypi.com/documentation/computers/configuration.html#i2c) menus and enable the serial port.

???+ note
	Not all of the advanced configuration options from the CLI are available in the Raspberry Pi Configuration GUI.

???+ tip "`config.txt. Method"
	If the I^2^C port is not enabled after rebooting your Pi, you can try to enable it by editing `/boot/firmware/config.txt`:

	- Edit `/boot/firmware/config.txt`

		```shell
		sudo nano /boot/firmware/config.txt
		```

	- Uncomment the line with `dtparam=i2c_arm=on`

		```shell
		# Uncomment some or all of these to enable the optional hardware interfaces
		dtparam=i2c_arm=on
		```

- Save the file using `crtl-X` and select `Save`

- Reboot the Pi with `sudo reboot`

## PyGPSClient
[PyGPSClient](https://github.com/semuconsulting/PyGPSClient) is a free, open-source graphical interface for GNSS receiver testing and evaluation. We recommend the software for the Raspberry Pi and other SBCs because it is supported on multiple operating systems. It also works very well on desktop machines too, if the GNSS module has a USB interface.

!!! info "System Requirements"
	The installation requires an internet connection to download the Python package from PyPI. Additionally, users will also need administrative privileges *(or root access `sudo`)* for the installation and [access the hardware connections](#enable-serial-interface). Other than this, no special privileges are required.

### Installation
There are a variety of [installation methods](https://github.com/semuconsulting/PyGPSClient?tab=readme-ov-file#installation) detailed in the GitHub repository's `README.md` file. However, we recommend utilizing either the [`pip` installation method](https://github.com/semuconsulting/PyGPSClient?tab=readme-ov-file#install-using-pip) or [installation shell script](https://github.com/semuconsulting/PyGPSClient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).

#### Shell Script
[Installation instructions](https://github.com/semuconsulting/PyGPSClient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) for the example shell scripts are detailed in the GitHub repository's `README.md` file.

<article style="text-align: center;" markdown>
[Example Installation Script](https://github.com/semuconsulting/PyGPSClient/blob/master/examples/pygpsclient_debian_install.sh "Go to file"){ .md-button .md-button--primary }
</article>

??? code "`pygpsclient_debian_install.sh`"
	```shell
	--8<-- "https://raw.githubusercontent.com/semuconsulting/PyGPSClient/refs/heads/master/examples/pygpsclient_debian_install.sh"
	```

#### `pip` Installation
[Installation instructions](https://github.com/semuconsulting/PyGPSClient?tab=readme-ov-file#install-using-pip) for the `pip` installation method are detailed in the GitHub repository's `README.md` file. Depending on how Python is installed on the computer, one of the following commands should allow users to install the software:

???+ tip "Jetson - Install `pip`"
	For the Jetson Orin Nano development kit, users will need to install `pip` before following the installation steps below.

	```shell
	sudo apt install python3-pip
	```

???+ rpi "Pi OS - Bookworm"
	Starting with Raspberry Pi OS Bookworm, users can no longer install Python packages, via `pip`, directly into the system version of Python. Instead, Python packages must be installed into a Python virtual environment (`venv`); a container where third-party modules can be safely installed without interfering with the system version of Python.

```shell
python3 -m pip install pygpsclient
```

```shell
pip3 install pygpsclient
```

### Virtual Environment
With the latest version of the Raspberry Pi OS, Bookworm, users will need to follow to the [instructions for utilizing a virtual environment](https://github.com/semuconsulting/PyGPSClient?tab=readme-ov-file#install-using-pip).

!!! warning
	Due to the nature of utilizing a virtual environment, these instructions will not function as a system wide installation. *(i.e. You'll only be able to access the application with the `<user>`, used to install the application in their virtual environment.)*

#### Create a Virtual Environment
To create a virtual environment, in a specific `<directory>`:

```shell
python3 -m venv <directory>
```

!!! example
	Creating a virtual environment in the `env` directory:

	```shell
	python3 -m venv env
	```

#### Activate the Virtual Environment
To activate the virtual environment that was created in the `<directory>`:

```shell
source <directory>/bin/activate
```

- **Install the Application in the Virtual Environment**

	Once inside the virtual environment, users can install the Python package with the normal `pip` installation command:

	```shell
	python3 -m pip install pygpsclient
	```

- **Run the Application in the Virtual Environment**

	To run the application in the virtual environment:

	```shell
	pygpsclient
	```

!!! example
	To install and run the the Python package inside the `env` virtual environment:

	```shell
	source env/bin/activate
	python3 -m pip install pygpsclient
	pygpsclient
	```

#### Deactivate the Virtual Environment
To deactivate the virtual environment:

```shell
deactivate
```

- Once deactivated, the virtual environment can be reactivated with the activation command:

	```shell
	source <directory>/bin/activate
	```

- To reactivate and run the Python package in the virtual environment:

	```shell
	source <directory>/bin/activate
	pygpsclient
	```

	!!! example
		```shell
		source env/bin/activate
		pygpsclient
		```

### Enable User Port
In certain circumstances, users may need to manually configure the serial port for the application to function.

- **Pi 3/4/Zero 2W:**

	```shell
	sudo pygpsclient ---userport /dev/ttyS0
	```

- **Pi 5:**

	```shell
	sudo pygpsclient ---userport /dev/ttyAMA0
	```

### Launch Options
While not required to operate the `PyGPSClient` software, user have additional options for how the Python package is executed.

- To operate the software outside of a virtual environment, users can add the directory of the software's binaries to the `PATH` variable.
- To utilize the software without an open terminal to be open, users can create a desktop application launcher.

#### Locate Relevant Binaries
The location of the relevant binaries folder can usually be found by executing one of the following commands:

- If the package was installed in the virtual environment, activate it:

	```shell
	source <directory>/bin/activate
	```

- For a global installation, execute the following command:

	```shell
	python3 -c "import os,sysconfig;print(sysconfig.get_path('scripts'))"
	```

	The system should return the following directory for the relevant binaries, in a virtual environment:

	```shell
	/home/<user>/<directory>/bin
	```

- Deactivate, if inside a virtual environment:

	```shell
	deactivate
	```

!!! example
	For a virtual environment, to find the directory of the relevant binaries execute the following commands:

	```shell
	source env/bin/activate
	python3 -c "import os,sysconfig;print(sysconfig.get_path('scripts'))"
	deactivate
	```

<!-- Not a user installation!
Then, execute the following command for a user installation:
```shell
python3 -c "import os,sysconfig;print(sysconfig.get_path('scripts',f'{os.name}_user'))"
```

The system should return the following directory for the relevant binaries:
```shell
/home/<user>/.local/bin
```
-->

#### Add to `PATH` Variable
To make the Python package accessible outside of the virtual environment, the directory of the relevant binaries need to be added to the `PATH` variable:

```shell
export PATH="$PATH:<directory to relevant binaries>"
source ~/.profile
```

!!! example

	```shell
	export PATH="$PATH:/home/pi/env/bin"
	source ~/.profile
	```

Once added, the application should now be available outside of the virtual environment:

```shell
pygpsclient
```

<!-- Not a user installation!
!!! example
	```shell
	export PATH="$PATH:/home/<user>/.local/bin"
	```

	```shell
	export PATH="$PATH:~/.local/bin"
	```
-->

<!-- Application is not available system wide
```shell
source /etc/environment
```

```shell
source /etc/profile
```
-->

#### Application Launcher
In addition to the previous sections, users can [follow these instructions](https://github.com/semuconsulting/PyGPSClient/blob/master/APPLAUNCH.md) to create an application launcher.

1. Create a text file named `pygpsclient.desktop` with the following content and save it in the `/home/<user>/.local/share/applications` directory.

	```shell
	[Desktop Entry]
	Type=Application
	Terminal=false
	Name=PyGPSClient
	Icon=/home/<user>/.local/lib/<python version>/site-packages/pygpsclient/resources/pygpsclient.ico
	Exec=/home/<user>/.local/bin/pygpsclient
	```

	!!! example
		```shell
		[Desktop Entry]
		Type=Application
		Terminal=false
		Name=PyGPSClient
		Icon=/home/pi/.local/lib/python3.13/site-packages/pygpsclient/resources/pygpsclient.ico
		Exec=/home/pi/.local/bin/pygpsclient
		```

	!!! tip
		Users can also validate the file, with the following command:

		```shell
		desktop-file-validate <file_name>.desktop
		```

1. Logout and back in for the changes to take effect.

### NTRIP Client

<div class="grid" markdown>

<div markdown>

<figure markdown>
NTRIP server configurations
<figcaption markdown>Configuration settings for connecting to an NTRIP client.</figcaption>
</figure>

</div>

<div markdown>

To receive and process NTRIP RTK correction data from an NTRIP server in the PyGPSClient software, users can follow [these instructions](https://github.com/semuconsulting/PyGPSClient?tab=readme-ov-file#ntrip-client-facilities):

1. Click on the :material-satellite-uplink: icon, labeled `NTRIP Client`.
1. Enter the information for the network and mount point.
	- For an NTRIP server hosted by the `PyGPSClient` software:
		- **Server:** IP address of Pi
		- **Port:** `2101`
		- **Mountpoint:** `pygnssutils`
		- **User:** `anon`
		- **Password:** `password`
1. Click on the :material-play: icon to connect to the server.

</div>

</div>

### NTRIP Server

<div class="grid" markdown>

<div markdown>

<figure markdown>
NTRIP server configurations
<figcaption markdown>Configuration settings for an NTRIP caster.</figcaption>
</figure>

</div>

<div markdown>

If their GNSS receiver is supported by NTRIP sever feature of the PyGPSClient software, users can follow [these instructions](https://github.com/semuconsulting/PyGPSClient?tab=readme-ov-file#socket-server--ntrip-caster-facilities) to setup their Raspberry Pi to operate as an NTRIP sever:

1. In the settings console, scroll to the bottom and select `NTRIP CASTER` from the **Mode** drop-down menu.
1. Select the box for `Configure Base Station` and select the GNSS receiver from the drop-down menu.
1. Select a mode of operation for the base station and provide the necessary information.
1. Select the box for `Socket Server/NTRIP Caster`.

</div>

</div>

## mosaic-X5 - Internet Access
In order to receive or cast RTK corrections to/from a RTK network, such as NTRIP, the mosaic-X5 GNSS receiver will need access to the internet through the USB interface.

- Users will need to use the web interface to enable the `Outgoing Internet Access Over USB` from the **Communication** > **USB** drop-down menu of the navigation tabs.

	<article class="video-500px" style="margin: auto;">
	<iframe src="https://www.youtube.com/embed/bUt8cL9Ue1Y" title="Septentrio: Share internet connection with your GNSS / GPS receiver over USB" frameborder="0" allow="accelerometer; autoplay; clipboard-write; encrypted-media; gyroscope; picture-in-picture" allowfullscreen></iframe>
	</article>

- This also requires users to configure a [network bridge](https://en.wikipedia.org/wiki/Network_bridge) on the Raspberry Pi.

	<figure markdown>
	Configure Network Bridge
	<figcaption markdown>Editing the network connections to create a network bridge.</figcaption>
	</figure>

	1. Open the network connections menu by opening the network manager (i.e. &uarr;&darr; or :fontawesome-solid-wifi: icon on taskbar) and selecting **Advanced Options** > **Edit Connections**.

		<figure markdown>
		Network Manager
		<figcaption markdown>Editing the connections through the Raspberry Pi's **Network Manager**.</figcaption>
		</figure>

	1. Check the wired connections under **Ethernet** to locate the connection that lists **Device:** `usb0 ....` in its properties.

		<figure markdown>
		Network connections
		<figcaption markdown>Check the connections listed under **Ethernet**.</figcaption>
		</figure>

	1. For that network connection, select the **IP v4 Settings** tab and select `Shared to other computers` from the **Method** drop-down menu.

	1. Click **Save** to apply the changes.

	1. Reboot the Raspberry Pi.

	1. To determine the new IP address assigned to the mosaic-X5, click on network manager and select **Advanced Options** > **Connection Information**. Locate the IP address listed for the same wired connection.

		!!! info "New IP Address"
			Once a network bridge is enabled, the receiver will receive its IP address from the computer's DHCP server. Depending on the routing table, the module may no longer be reachable at its default IP address *(`192.168.3.1`)*.

			If users need to determine the subnet address of the network connection, they need to install a tool called `nmap`.

			```shell
			sudo apt install nmap -y
			```

			In a terminal enter the following command to determine IP address.

			```shell
			nmap <IP Address>/24
			```

			- With the `*/24` option, the program will scan all the **Class C** subnet addresses (i.e. from `A.B.C.x` through `A.B.C.255`)

		!!! tip
			If the mosaic is still not connecting, try resetting it. The assigned IP should not change after it has booted.

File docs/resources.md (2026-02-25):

## Product Resources

- Product Pages
	- :sfe: [SparkFun GNSS Flex pHAT](https://www.sparkfun.com/sparkfun-gnss-flex-phat.html)
	- :sfe: [SparkFun GNSS Flex pHAT - mosaic-X5](https://www.sparkfun.com/sparkfun-gnss-flex-phat-mosaic-x5.html)
	- :sfe: [SparkFun GNSS Flex pHAT - LG290P](https://www.sparkfun.com/sparkfun-gnss-flex-phat-lg290p.html)
	- :sfe: [SparkFun GNSS Flex pHAT - DAN-F10N](https://www.sparkfun.com/sparkfun-gnss-flex-phat-dan-f10n.html)
	- :sfe: [SparkFun GNSS Flex pHAT - LG290P & IM19](https://www.sparkfun.com/sparkfun-gnss-flex-phat-lg290p-im19-imu.html)
	- :sfe: [SparkFun GNSS Flex pHAT - ZED-X20P](https://www.sparkfun.com/sparkfun-gnss-flex-phat-zed-x20p.html)
	- :sfe: [SparkFun GNSS Flex pHAT - ZED-X20P & IM19](https://www.sparkfun.com/sparkfun-gnss-flex-phat-zed-x20p-im19-imu.html)
	- :sfe: [SparkFun GNSS Flex pHAT - LG580P](https://www.sparkfun.com/sparkfun-gnss-flex-phat-lg580p.html)
- :material-folder-cog: Design Files:
	- :fontawesome-solid-file-pdf: [Schematic](./assets/board_files/schematic.pdf)
	- :fontawesome-solid-file-pdf: [Board Dimensions](./assets/board_files/dimensions.pdf)
	- :material-folder-zip: [KiCad Files](./assets/board_files/kicad_files.zip)
	- :material-cube-outline: [STEP File](./assets/3d_model/cad_model.step)
- Component Documentation
	- :fontawesome-solid-file-pdf: [HAT+ Specification](./assets/component_documentation/hat-plus-specification.pdf)
	- :fontawesome-solid-file-pdf: [HAT+ Wordmark Guidelines](./assets/component_documentation/hat-plus-wordmark-guidelines.pdf)
	- :fontawesome-solid-file-pdf: [AP7361C LDO Datasheet](./assets/component_documentation/AP7361C.pdf)
	- :fontawesome-solid-file-pdf: [RT9080 LDO Datasheet](./assets/component_documentation/RT9080.pdf)
- PyGPSClient Software
	- :material-github: [GitHub Repository](https://github.com/semuconsulting/PyGPSClient)
	- :material-github: [Installation Instructions](https://github.com/semuconsulting/PyGPSClient?tab=readme-ov-file#installation)
	- :simple-pypi: [PyPI Project](https://pypi.org/project/pygpsclient/)
- :material-youtube: [Product Showcase](https://youtu.be/r-bhOLv4zsk)
- :material-github: [Hardware Repo](https://github.com/sparkfun/SparkFun_GNSS_Flex_pHAT)

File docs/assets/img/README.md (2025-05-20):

img directory
====================
This folder should contain the images for the product documentation

## General Images
- `sfe-logo.png` - SparkFun flame logo (favicon)

## Directory
- `graphical_datasheet` - Files for graphical datasheet
- `hookup_guide` - Images for the hookup guide pages
- `qr_code` - QR code images
- `qwiic` - Images for Qwiic Banner

## QR Codes
- [QR code generator](https://qrgenerator.org/)
	- Flame Color: #E0311D
	- Frame Color: #3C464D
- [Remove meta data from svg](https://jakearchibald.github.io/svgomg/)

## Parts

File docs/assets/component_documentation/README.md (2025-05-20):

SparkFun Documentation
=======================

This directory should include any necessary datasheets, example number crunching, etc.

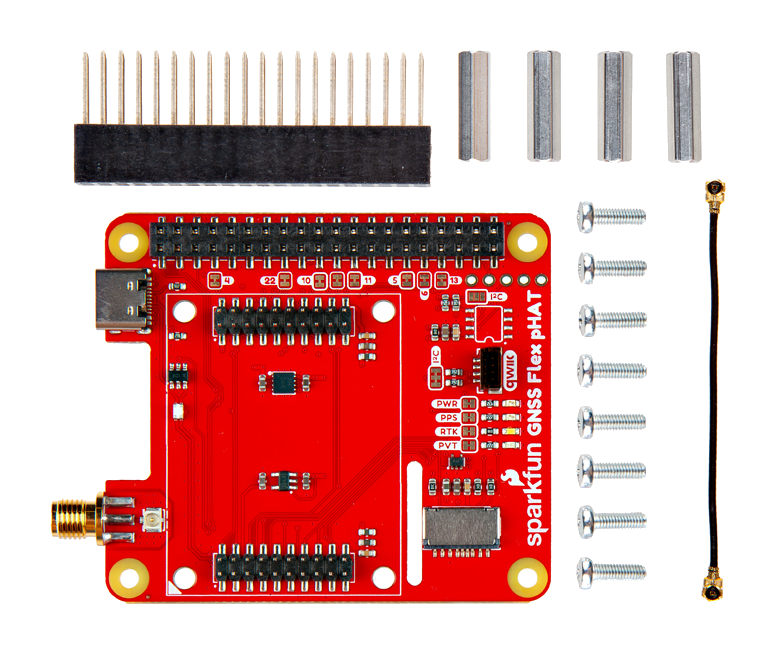
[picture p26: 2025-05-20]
docs/assets/img/hookup_guide/kit-parts.png

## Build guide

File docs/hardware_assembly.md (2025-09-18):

??? rpi "Raspberry Pi - Specific Instructions"
	The instructions below are specific to the Raspberry Pi and similar style SBCs. For other platforms, users should take into account the mechanical requirements of the SBC they are utilizing. For example, when interfacing the Nvidia Jetson Orin Nano, the pHAT will extend outside of the Jetson's footprint and can't be secured to the base.

	<figure markdown>
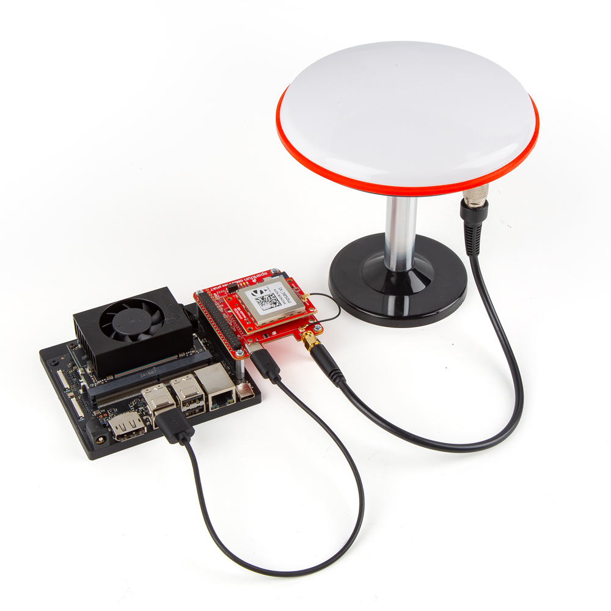
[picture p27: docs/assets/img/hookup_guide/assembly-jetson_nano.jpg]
	
	<figcaption markdown>Setting up the GNSS Flex pHAT kit with a Nvidia Jetson Orin Nano.</figcaption>
	</figure>

??? tip "Kit Components"
	Below, are the minimum parts that users will need to assemble the GNSS Flex pHAT on a Raspberry Pi or similar SBC.

	<div class="grid" markdown>

	<div markdown>

	<figure markdown>
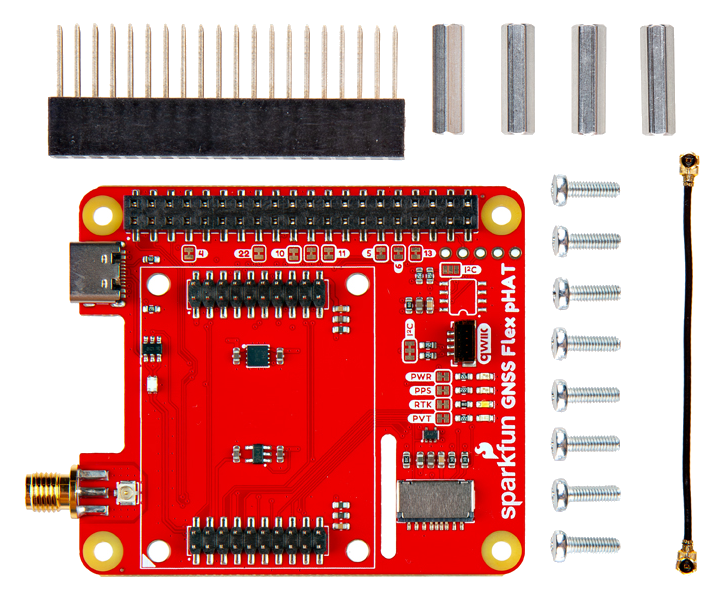
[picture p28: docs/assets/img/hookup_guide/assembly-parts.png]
Included part
	
	<figcaption markdown>The accessories included in addition to the GNSS Flex module, as part of the GNSS Flex pHAT kit.</figcaption>
	</figure>

	</div>

	<div markdown>

	**Parts List**

	---

	- x1 - [SparkFun GNSS Flex pHAT](https://www.sparkfun.com/sparkfun-gnss-flex-phat.html)
	- x1 - [Tall GPIO Female Headers - 2x20 Pin](https://www.sparkfun.com/tall-gpio-female-headers-2x20-pin.html)
	- x1 - [50mm U.FL to U.FL Cable](https://www.sparkfun.com/u-fl-to-u-fl-mini-coax-cable-50mm.html)
	- x4 - Aluminum Hex Standoff
		- Thread: M2.5-0.45; Length: 16mm
	- x8 - Phillips Machine Screw
		- Thread: M2.5-0.45x8mm

	</div>

	</div>

## External Antenna
In order to receive [GNSS](https://en.wikipedia.org/wiki/Satellite_navigation "Global Navigation Satellite System") signals, users will need a compatible antenna. For the best performance, we recommend an active L1/L2/L5/L6/L-band GNSS antenna for most of our GNSS Flex modules.

<figure markdown>
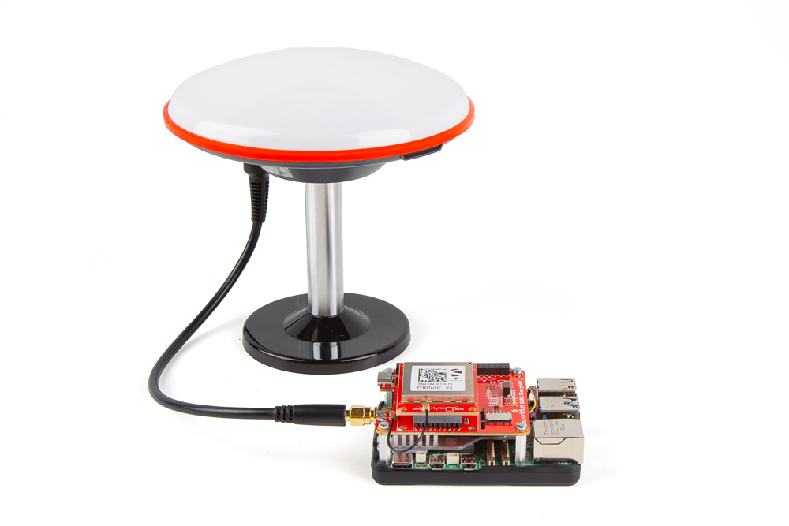
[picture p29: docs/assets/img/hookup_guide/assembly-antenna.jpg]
Antenna connection

<figcaption markdown>Connecting an antenna to the GNSS Flex pHAT.</figcaption>
</figure>

!!! tip
	For the best performance, we recommend users choose a compatible L1/L2/L5/L6 GNSS antenna and utilize a low-loss cable. Also, don't forget that GNSS signals are fairly weak and can't penetrate buildings or dense vegetation. The GNSS antenna should have an unobstructed view of the sky.

	!!! note
		Please keep in mind that these are general suggestions for our GNSS Flex modules. Some of these boards may have multiple GNSS antenna connections, an integrated antenna, support specific frequency bands, etc. For more details on a specific GNSS Flex module, please refer to their [hookup guide](../modules.md).

### Connection Options
There are two options for connecting an external antenna to a GNSS Flex module:

- An external antenna can be connected through the U.FL connector on the GNSS Flex pHAT.
- However, for a sturdier connection, there is a signal pass-through between the U.FL and SMA antenna connectors on the GNSS Flex pHAT. To utilize the SMA connector, users can bridge the U.FL connections between the boards with a U.FL cable.

<div class="grid" markdown>

<div markdown>

<figure markdown>
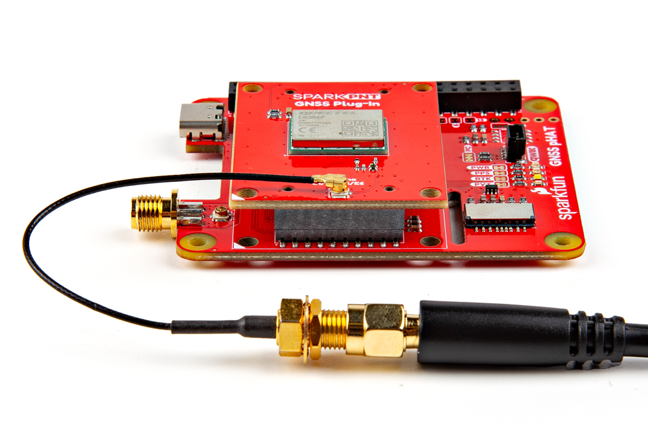
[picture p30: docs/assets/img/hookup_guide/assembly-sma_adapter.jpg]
Antenna connection with SMA adapter

<figcaption markdown>Attaching an antenna directly to the GNSS Flex module with an adapter cable.</figcaption>
</figure>

</div>

<div markdown>

<figure markdown>
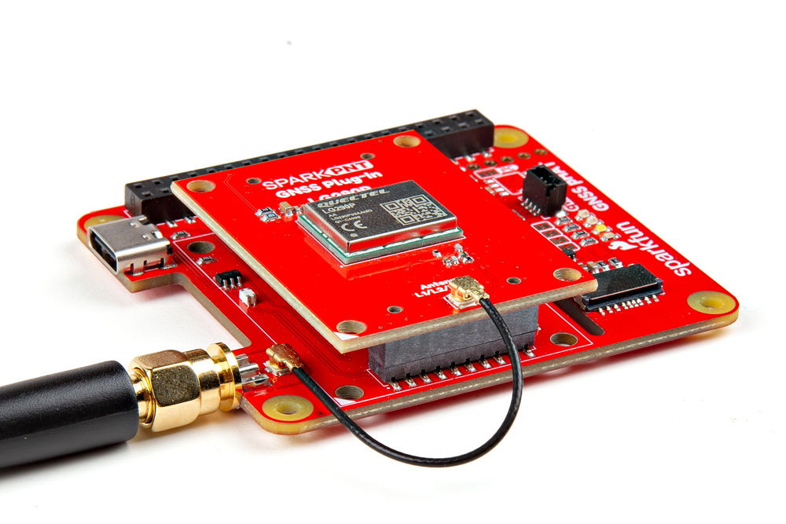
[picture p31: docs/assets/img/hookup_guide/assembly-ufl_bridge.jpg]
Antenna connection to the pHAT

<figcaption markdown>Bridging the U.FL connectors on the boards, to utilize the SMA connector on the GNSS Flex pHAT.</figcaption>
</figure>

</div>

</div>

### Signal Bridge
The signal bridge on the GNSS Flex pHAT can be utilized to connect an external antenna to the SMA connector. For the connection to work, an U.FL cable needs to bridge the antenna connection from the GNSS Flex module to the GNSS Flex pHAT. Due to the space constraint, we recommend connecting the U.FL cable to the GNSS Flex pHAT before attaching the GNSS Flex module to the pHAT.

<div class="grid" markdown>

<div markdown>

<figure markdown>
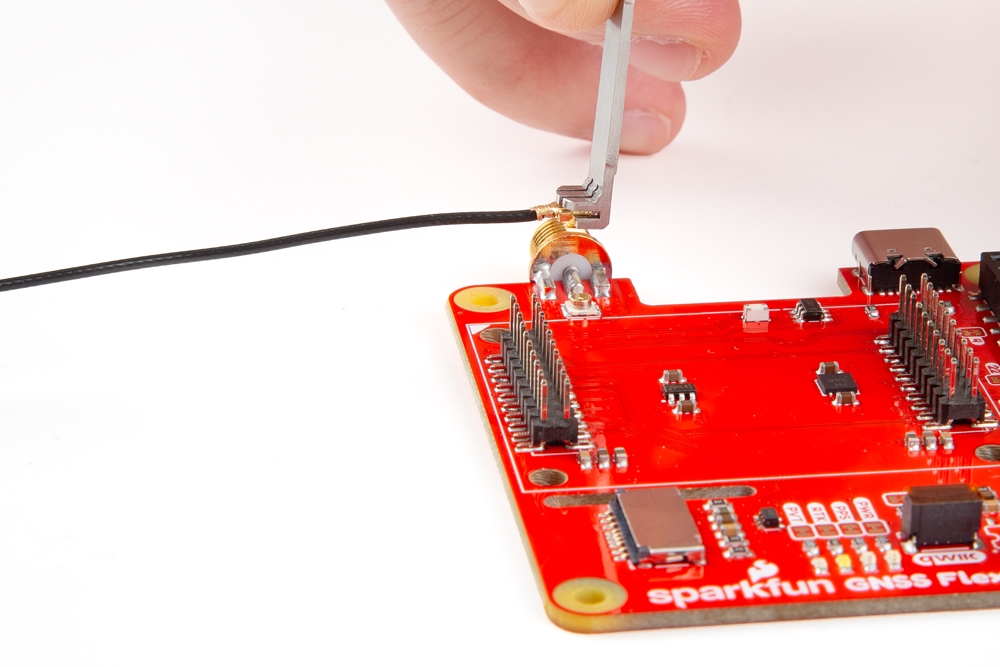
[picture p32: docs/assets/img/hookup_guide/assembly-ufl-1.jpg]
U.FL cable attached to pHAT

<figcaption markdown>Step 1 - Connect the U.FL cable to the GNSS Flex pHAT.</figcaption>
</figure>

</div>

<div markdown>

<figure markdown>
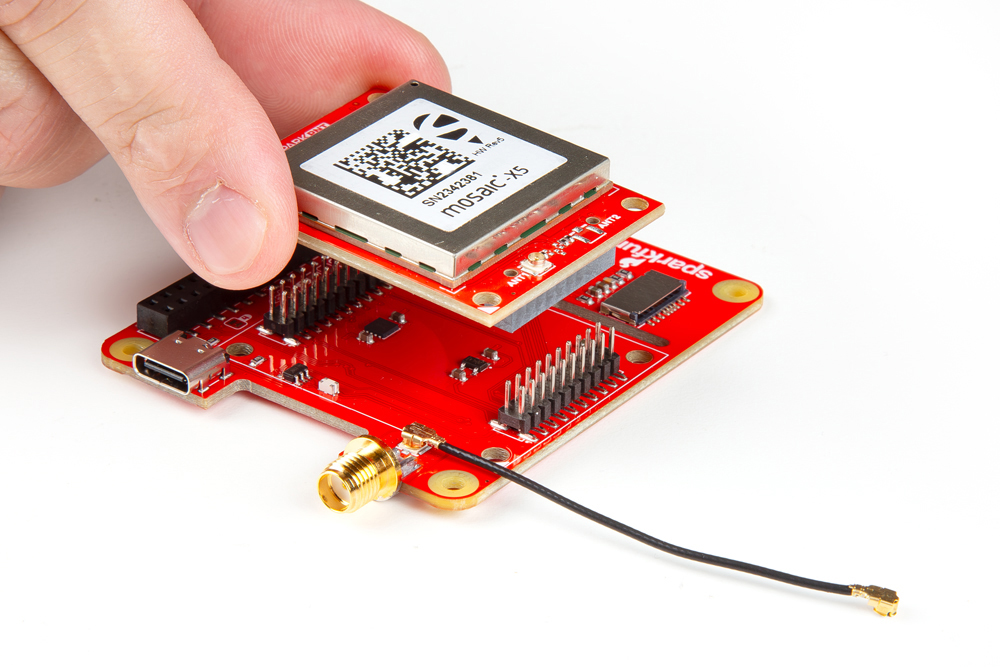
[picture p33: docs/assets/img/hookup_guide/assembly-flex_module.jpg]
Attaching GNSS Flex module to pHAT

<figcaption markdown>Step 2 - Attach the GNSS Flex module to the pHAT.</figcaption>
</figure>

</div>

<div markdown>

<figure markdown>
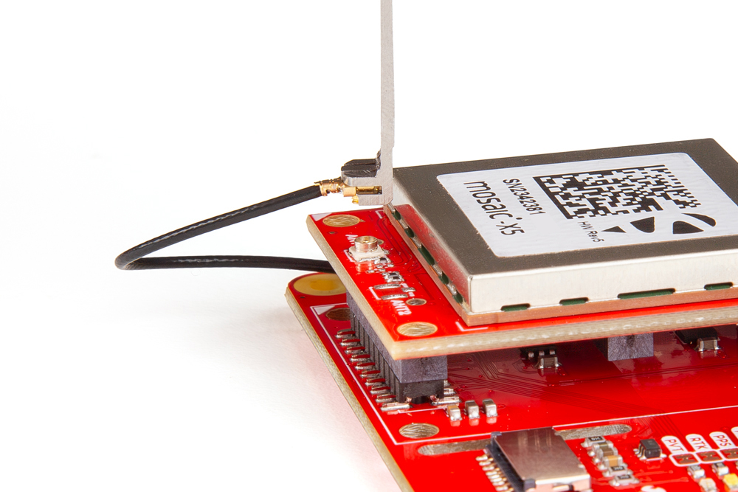
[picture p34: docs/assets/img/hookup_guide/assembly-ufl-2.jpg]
U.FL cable attached to GNSS Flex module

<figcaption markdown>Step 3 - Connect the other end of the U.FL cable to the GNSS Flex module.</figcaption>
</figure>

</div>

<div markdown>

<figure markdown>
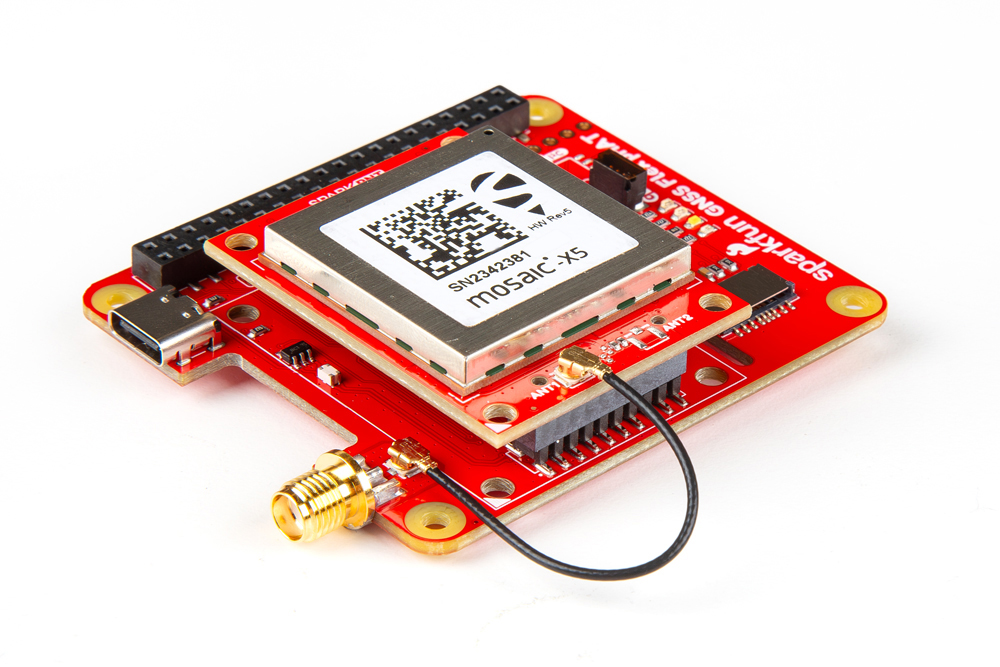
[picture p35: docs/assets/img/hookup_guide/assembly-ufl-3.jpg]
Antenna connection bridged

<figcaption markdown>A U.FL cable bridging the antenna connection between the boards.</figcaption>
</figure>

</div>

</div>

## GNSS Flex Module
The GNSS Flex system is a modular ecosystem designed around two 2x10-pin, 2mm pitch headers, so boards are pin-compatible for upgrades and easily swapped for repairs. Users simply, stack a SparkPNT GNSS Flex module onto the headers of its associated *carrier* board.

!!! tip "SMA Connector"
	When bridging the antenna connection to the SMA connector of the GNSS Flex pHAT, we recommend attaching the U.FL cable to the pHAT before the GNSS Flex module.

<figure markdown>
Attaching GNSS Flex module to pHAT
<figcaption markdown>Attaching a GNSS FLex module to the GNSS Flex pHAT.</figcaption>
</figure>

### Board Alignment
The alignment indicator for mating these boards, is annotated with a triangle in the corner of the mating area.

<figure markdown>
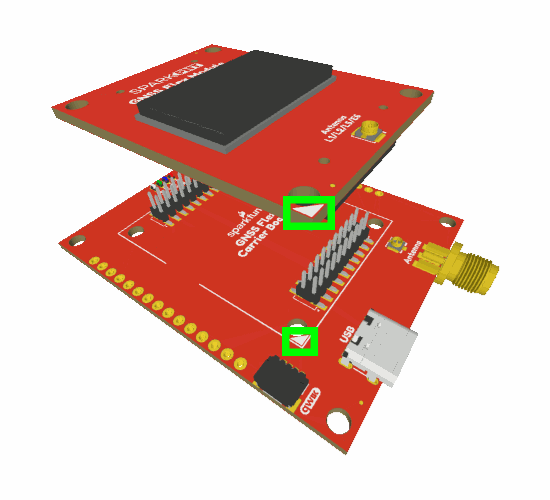
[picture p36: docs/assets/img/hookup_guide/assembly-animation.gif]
Flex system board mating

<figcaption markdown>The alignment and connection of a SparkPNT GNSS Flex module on top of a *carrier* board.</figcaption>
</figure>

## Assemble pHAT
Before assembling the mechanical hardware for the GNSS Flex pHAT, users should consider how the hardware will interface with their Raspberry Pi or other SBC.

- Attach the extension header to the Raspberry Pi or other single-board computer
- Attach the screws and standoffs to the SparkFun GNSS Flex pHAT
	1. To make things easier, we recommend attaching the standoffs to the pHAT first
	1. Once attached, users can stack the pHAT onto the Raspberry Pi or other single-board computer
	1. For a more permanent installation, users can also secure the pHAT to the SBC from the base

### Header Extension
When assembling the GNSS Flex pHAT, users should utilize the extension header that best suits their needs.

<figure markdown>
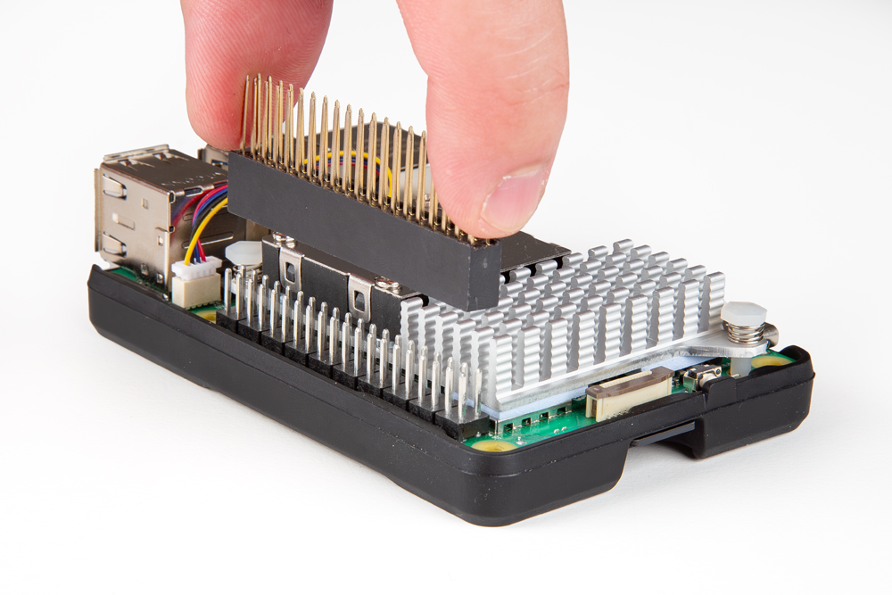
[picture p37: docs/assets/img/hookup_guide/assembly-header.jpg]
Attaching the extension header to a Pi

<figcaption markdown>Attaching the extension header to the GPIO pins on a Raspberry Pi.</figcaption>
</figure>

!!! tip "Stacking Multiple HATs"
	<div class="grid" markdown>

	<div markdown>

	<figure markdown>
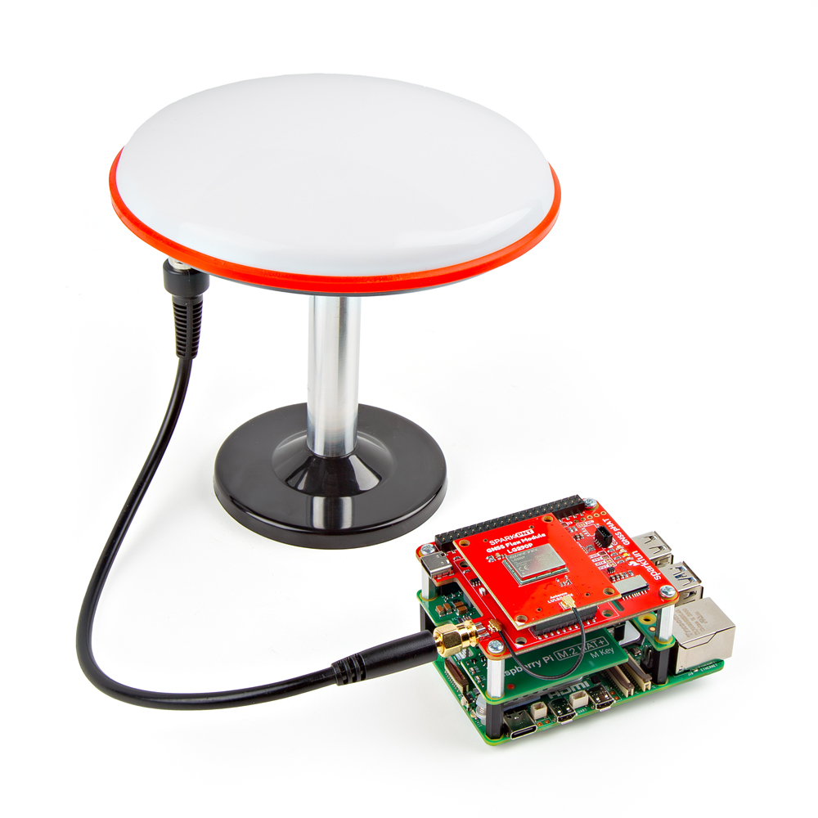
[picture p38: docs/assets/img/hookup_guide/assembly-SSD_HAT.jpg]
Extension headers
	
	<figcaption markdown>Using different extension headers to stack multiple HATs on a Raspberry Pi.</figcaption>
	</figure>

	</div>

	<div markdown>

	**Selecting an Extension Header**

	---

	- [Tall GPIO Female Headers - 2x20 Pin](https://www.sparkfun.com/tall-gpio-female-headers-2x20-pin.html)
		- These are the same extension headers included in our GNSS Flex pHAT kits.
		- These headers are just long enough to attach a Raspberry Pi HAT/pHAT and are great if you are looking to maximize the amount of airflow beneath the pHAT.
	- [Extended GPIO Female Header - 2x20 Pin (16mm/7.30mm)](https://www.sparkfun.com/extended-gpio-female-header-2x20-pin-16mm-7-30mm.html)
		- These headers offer the most structural support and are long enough for stacking multiple HATs, but with the spacers it's just a little too tall to match the height of the standoffs in the kit.
	- [Extended GPIO Female Header - 2x20 Pin (13.5mm/9.80mm)](https://www.sparkfun.com/extended-gpio-female-header-2x20-pin-13-5mm-9-80mm.html)
		- These headers are great if users want to stack multiple Raspberry Pi HAT/pHATs.

	</div>

	</div>

### Standoffs
The standoffs included in the GNSS Flex pHAT kits offer structural support and ventilation space, for attaching the board to a Raspberry Pi. However, an extension header must be used in order to maintain the pin connections of the 40-pin GPIO header from the Raspberry Pi.

When connecting the standoffs, we recommend attaching them to the GNSS Flex pHAT first. However, users should leave the screws a little loose to account for minor tolerances in the mechanical assembly.

<div class="grid" markdown>

<div markdown>

<figure markdown>
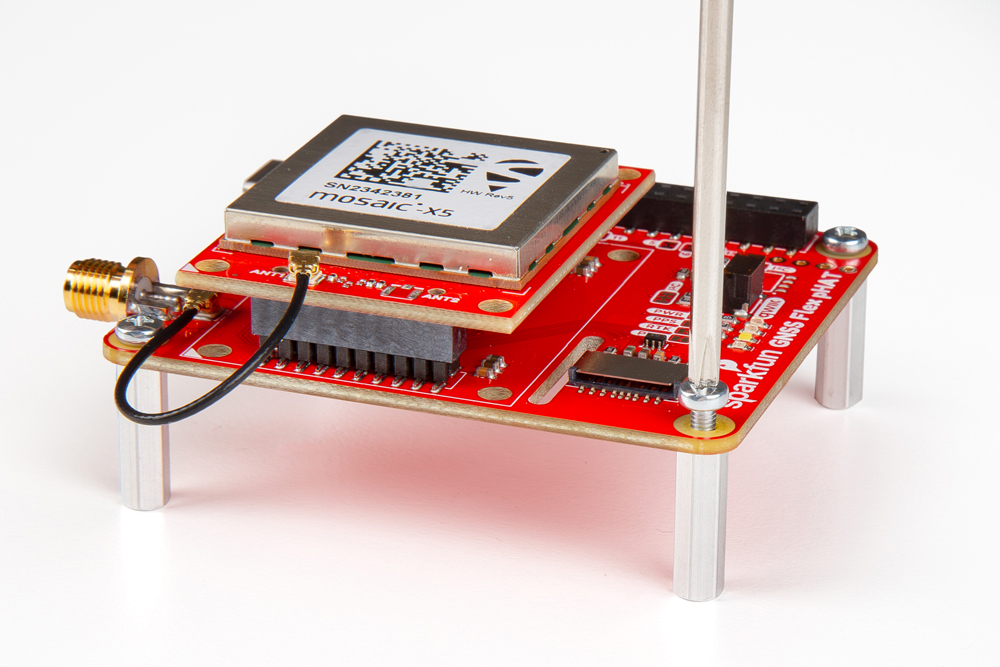
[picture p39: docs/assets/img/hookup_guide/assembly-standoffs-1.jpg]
Connecting standoffs to the pHAT

<figcaption markdown>Attaching the standoffs to the GNSS Flex pHAT with a screwdriver.</figcaption>
</figure>

</div>

<div markdown>

<figure markdown>
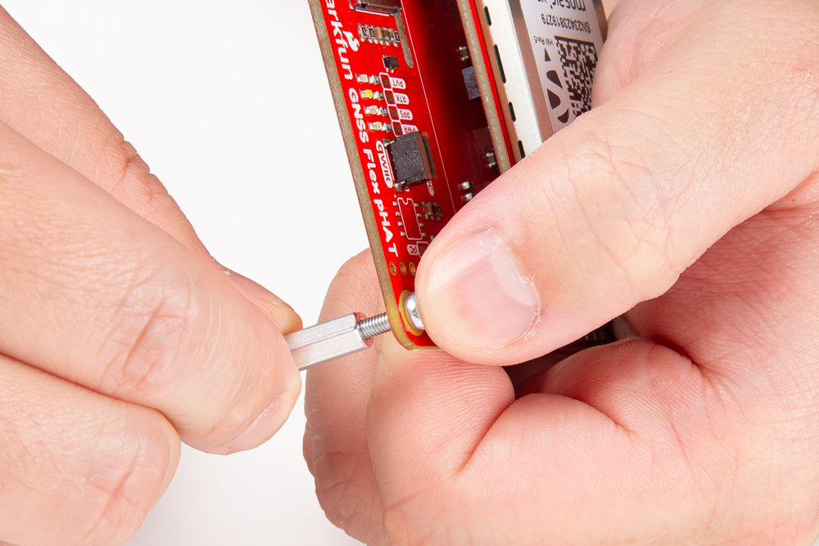
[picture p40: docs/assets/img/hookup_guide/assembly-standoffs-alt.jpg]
Alternative method of attaching standoffs

<figcaption markdown>A more effective method for initially connecting the standoffs.</figcaption>
</figure>

</div>

</div>

Once users have attached the standoffs to the GNSS Flex pHAT, it can be stacked onto the GPIO header of the Raspberry Pi and secured to the board.

<div class="grid" markdown>

<div markdown>

<figure markdown>
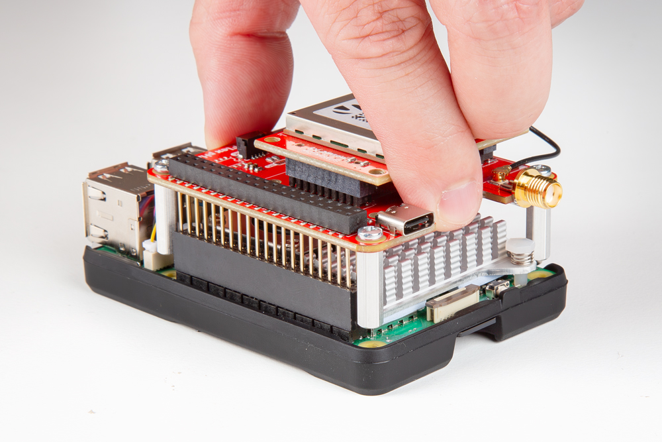
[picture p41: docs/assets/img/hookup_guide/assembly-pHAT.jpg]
Attaching pHAT to a Pi

<figcaption markdown>Attaching GNSS Flex pHAT to the extension header on the GPIO pins on a Raspberry Pi.</figcaption>
</figure>

</div>

<div markdown>

<figure markdown>
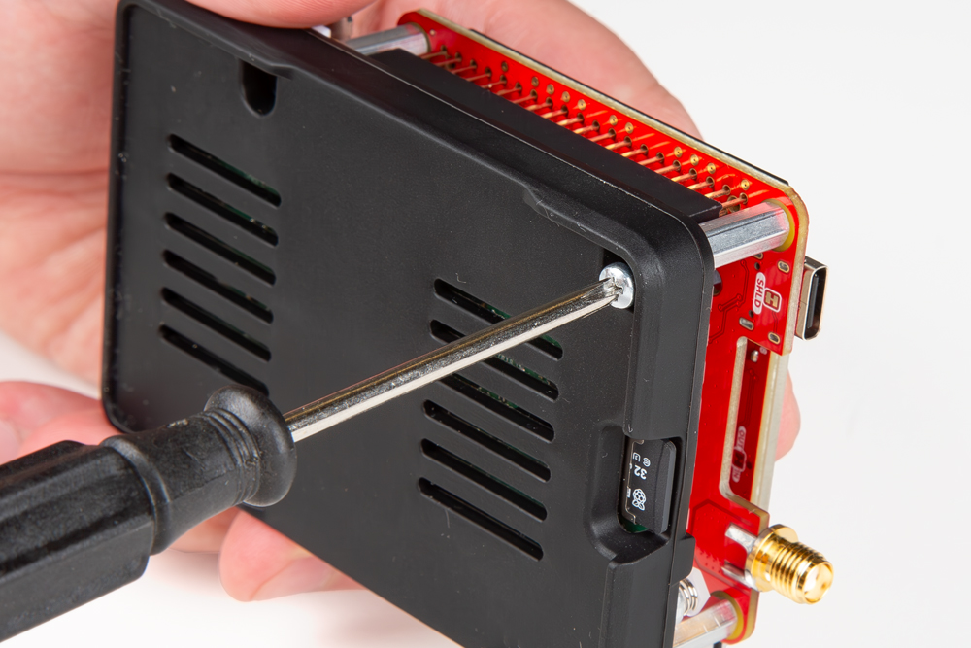
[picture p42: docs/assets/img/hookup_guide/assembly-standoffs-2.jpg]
Connecting screws to base of the board

<figcaption markdown>Securing the standoffs to the base of the Raspberry Pi.</figcaption>
</figure>

</div>

</div>

## USB Connector
If the GNSS Flex module has the capability, a USB-C connector is provided on the GNSS Flex pHAT to interface with the GNSS receiver. However, depending on the software support of the GNSS receiver, users can either interface with the GNSS receiver directly from the Raspberry Pi or externally from another computer.

<div class="grid" markdown>

<div markdown>

<figure markdown>
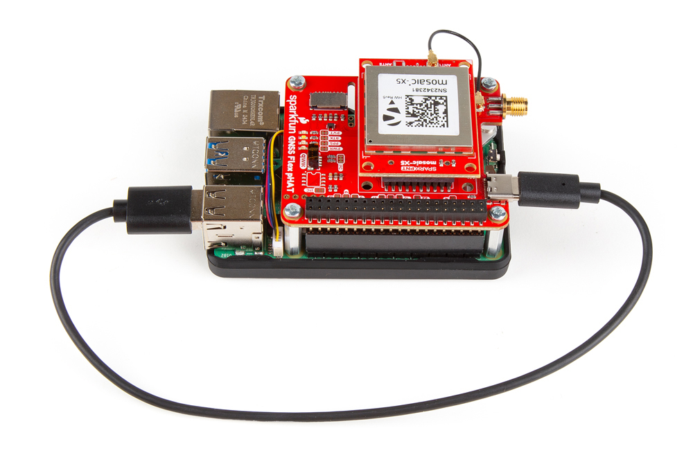
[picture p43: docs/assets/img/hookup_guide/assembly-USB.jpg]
USB connection - Pi

<figcaption markdown>Connecting the USB interface of the GNSS Flex module directly to the Raspberry Pi.</figcaption>
</figure>

</div>

<div markdown>

<figure markdown>
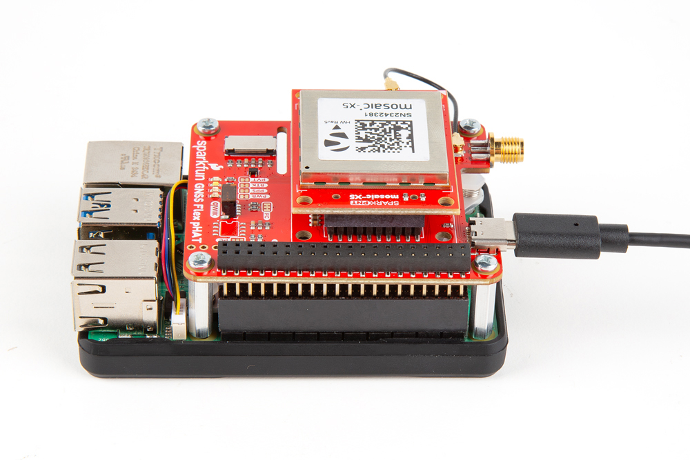
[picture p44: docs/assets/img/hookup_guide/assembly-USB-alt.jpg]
USB connection - External

<figcaption markdown>Connecting the USB interface of the GNSS Flex module to an external computer.</figcaption>
</figure>

</div>

</div>

## SD Card Slot
If the GNSS Flex module has the capability, an SD card slot is provided on the GNSS Flex pHAT for data logging.

<figure markdown>
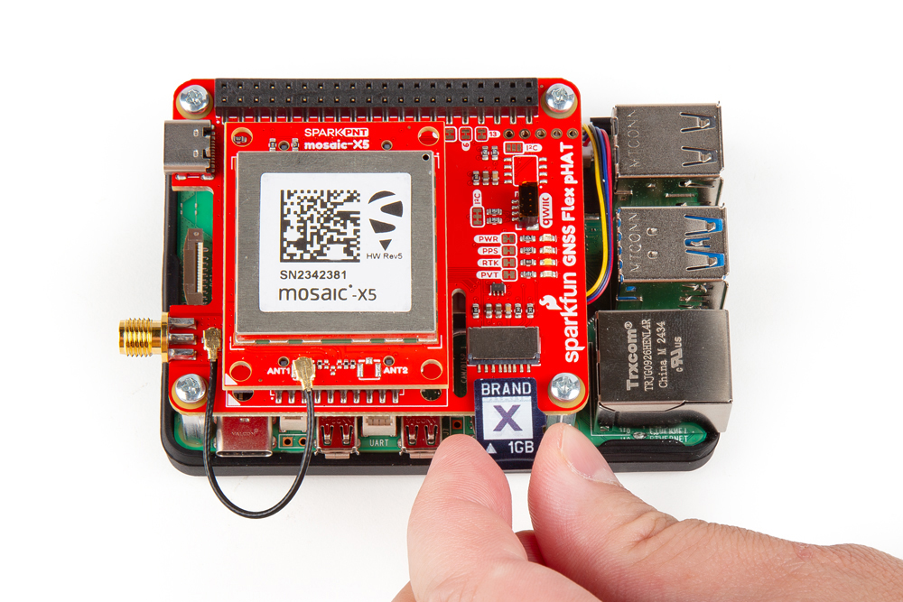
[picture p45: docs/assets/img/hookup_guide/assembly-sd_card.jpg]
USB connection

<figcaption markdown>Jumpers on the bottom of the GNSS Flex pHAT.</figcaption>
</figure>

## Qwiic Devices
The Qwiic system allows users to effortlessly prototype with a Qwiic compatible I^2^C device without soldering. Users can connect Qwiic [sensors or boards](https://www.sparkfun.com/special-categories/qwiic.html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) with just a few [Qwiic cables](https://www.sparkfun.com/sparkfun-qwiic-cable-kit.html). *(The example below, is for demonstration purposes and is not pertinent to the board functionality or this tutorial.)*

<figure markdown>
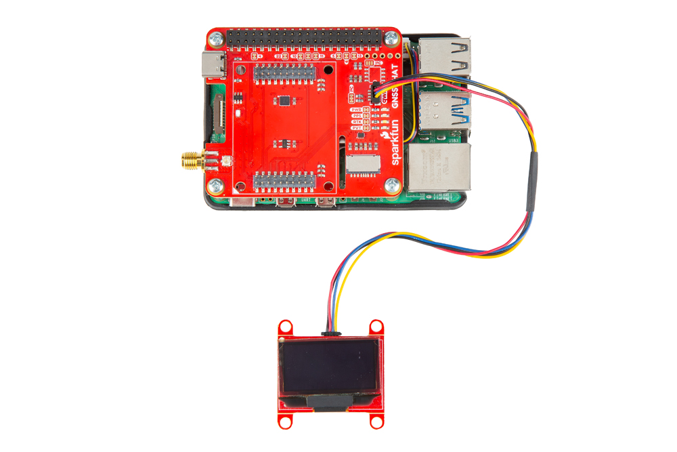
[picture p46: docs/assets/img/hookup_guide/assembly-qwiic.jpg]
Qwiic devices connected

<figcaption markdown>A Qwiic OLED display connected to the GNSS Flex pHAT.</figcaption>
</figure>

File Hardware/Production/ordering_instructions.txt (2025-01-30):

Ordering Instructions:
Panel dimensions: 149.28 x 127.70 mm.
Controlled Impedance: JLC7628
Material: TG155
Solder Mask: Red
Silkscreen Color: White
Layers: 4
Finish: ENIG
Thickness: 1.6mm
Inner Copper Weight: 0.5oz
Outer Copper Weight: 1oz
Minimum track width: 0.15mm (6.00mil)
Minimum via drill: 0.30mm (12.00mil)
No Clean Process

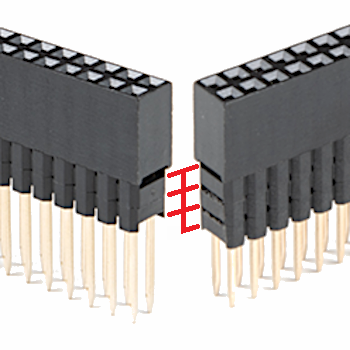
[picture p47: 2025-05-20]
docs/assets/img/hookup_guide/comparison-extension_header.png

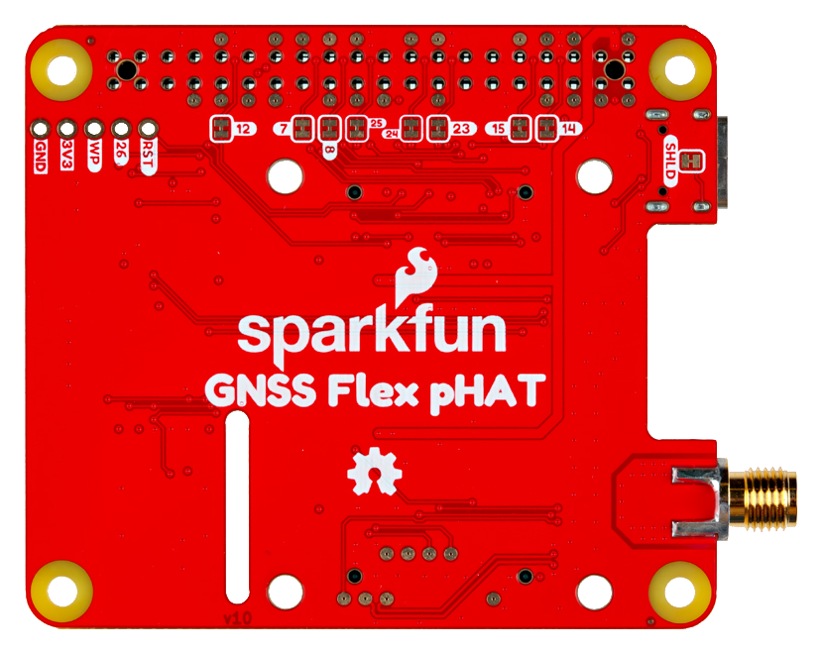
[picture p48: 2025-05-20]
docs/assets/img/hookup_guide/bottom.png

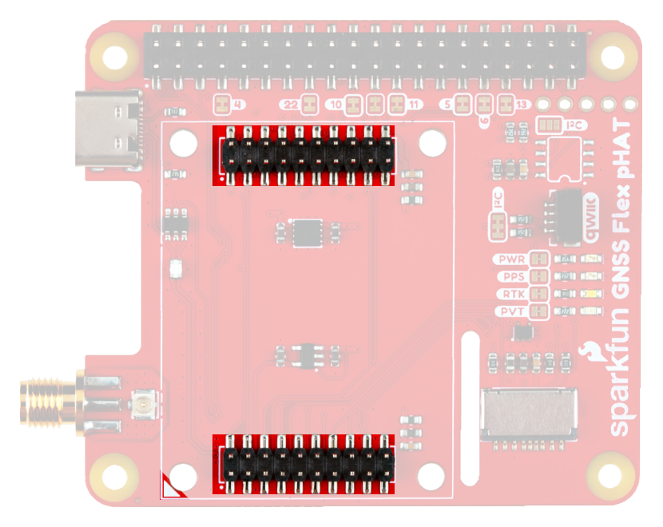
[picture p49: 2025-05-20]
docs/assets/img/hookup_guide/headers-flex_system.png

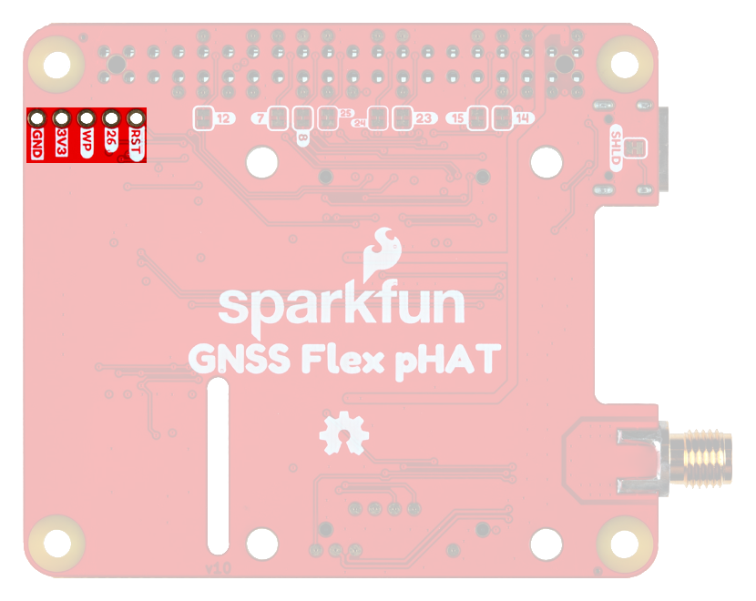
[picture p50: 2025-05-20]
docs/assets/img/hookup_guide/pins.png

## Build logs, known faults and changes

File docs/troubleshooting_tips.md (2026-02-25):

!!! warning "Need Help?"
	If you need technical assistance or more information on a product that is not working as you expected, we recommend heading on over to the [SparkFun Forums](https://community.sparkfun.com).

	!!! info "Account Registration Required"
		If this is your first visit to our forum, you'll need to create a [Forum Account](https://community.sparkfun.com/signup) to post questions.

!!! tip "Is PyGPSClient disconnecting?"
	If PyGPSClient disconnects from the serial port after a few seconds, you probably still have the Login Shell enabled. Use 'raspi-config' to ensure: the serial port hardware is enabled; and that [the login shell is *not* accessible](https://www.raspberrypi.com/documentation/computers/configuration.html#disabling-the-linux-serial-console).

## PyGPSClient *(system wide access)*
Users could potentially make the pyGPSCLient application globally available on the Raspberry Pi; however, that is outside the scope of this document.

!!! tip
	For some tips, users can check out these recommendations on [stackoverflow](https://stackoverflow.com/a/78652149)

## PyGPSClient Dependencies
For those not interested in the GUI, but would still like to access its functionality, the libraries of the the `PyGPSClient` Python package are listed below:

- [pynmeagps](https://github.com/semuconsulting/pynmeagps) - a parser and generator for NMEA 0183 protocol messages.
- [pyubx2](https://github.com/semuconsulting/pyubx2) - a parser and generator for u-blox UBX protocol messages.
- [pyrtcm](https://github.com/semuconsulting/pyrtcm) - a parser for RTCM protocol messages.
- [pyspartn](https://github.com/semuconsulting/pyspartn) - a parser for SPARTN protocol messages.
- [pygnssutils](https://github.com/semuconsulting/pygnssutils) - a series of GNSS utility libraries, including NTRIP and SPARTN clients, an NTRIP caster and a `gnssstreamer` utility which has broadly comparable functionality to `gpsd`.
- [pyubxutils](https://github.com/semuconsulting/pyubxutils) - a series of UBX utllities.

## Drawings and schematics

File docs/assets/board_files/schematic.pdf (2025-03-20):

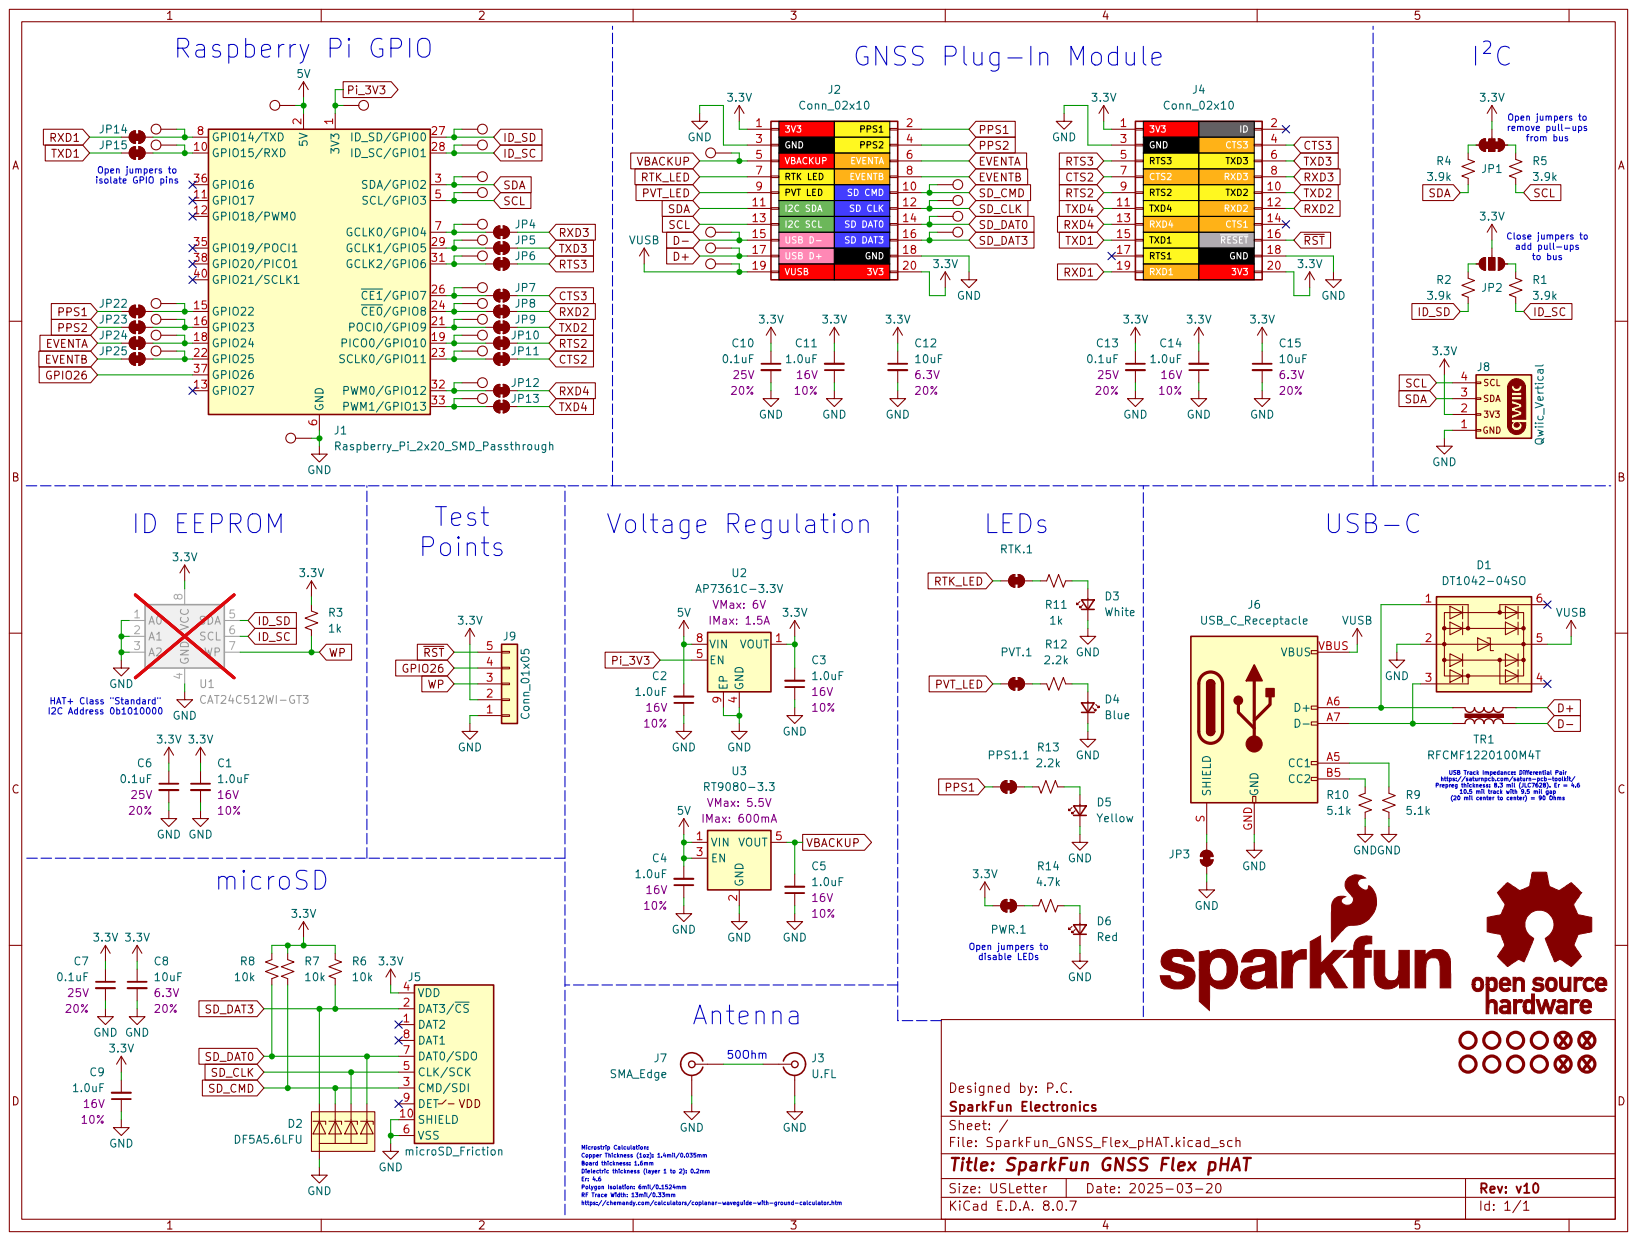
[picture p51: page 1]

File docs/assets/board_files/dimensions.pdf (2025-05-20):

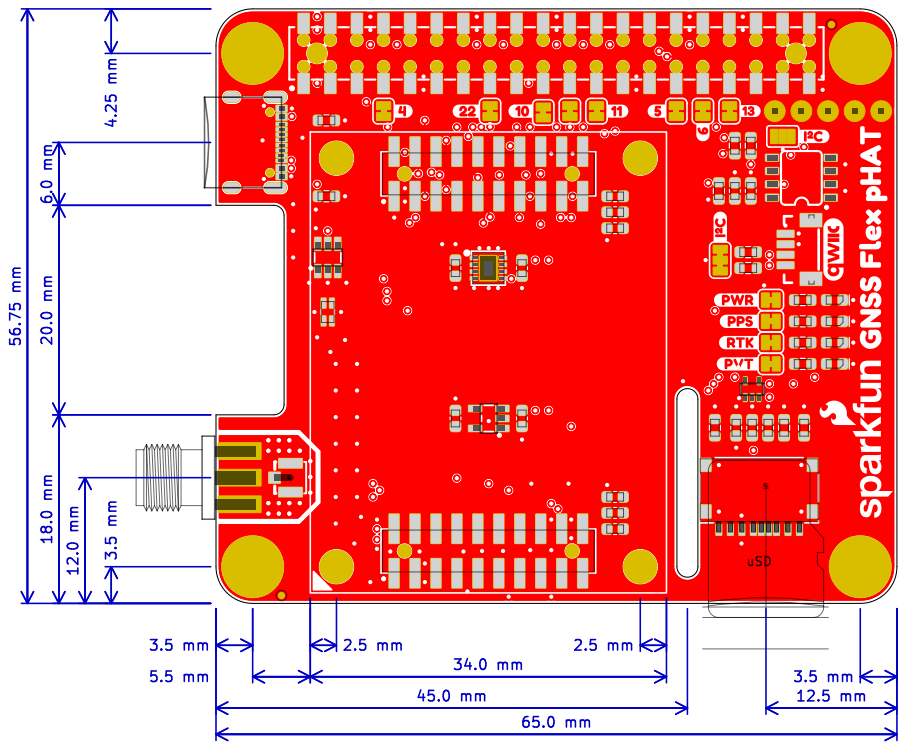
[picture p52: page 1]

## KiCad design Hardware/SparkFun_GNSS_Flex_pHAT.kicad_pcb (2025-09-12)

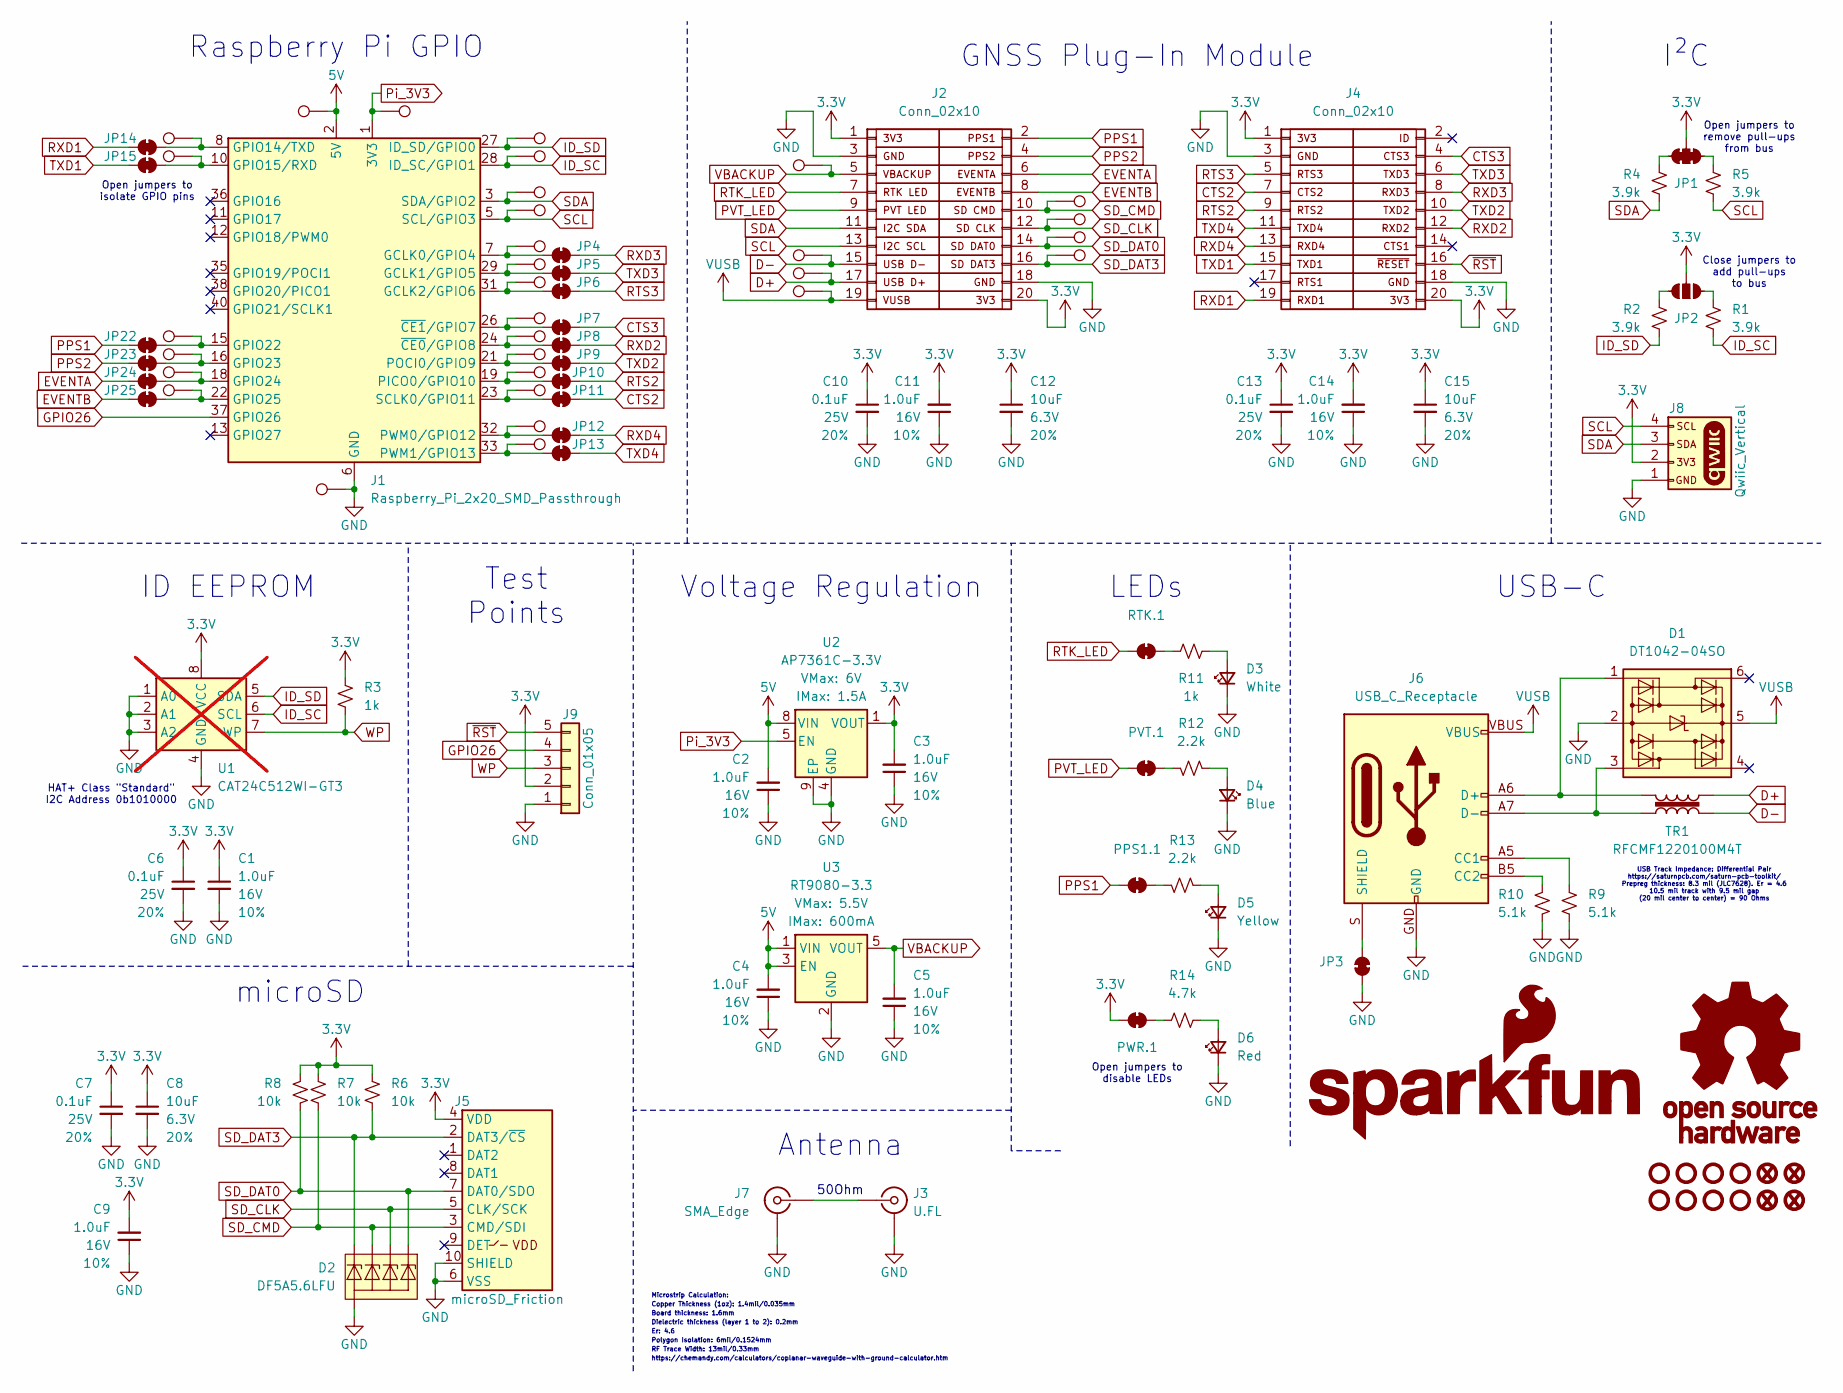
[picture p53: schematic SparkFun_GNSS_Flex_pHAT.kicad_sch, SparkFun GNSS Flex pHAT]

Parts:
C1, C2, C3, C4, C5, C9, C11, C14: 1.0uF; C_0603_1608Metric; Voltage 16V; Tolerance 10%
C6, C7, C10, C13: 0.1uF; C_0603_1608Metric; Voltage 25V; Tolerance 20%
C8, C12, C15: 10uF; C_0603_1608Metric; Voltage 6.3V; Tolerance 20%
D1: DT1042-04SO; SOT23-6
D2: DF5A5.6LFU; SOT-353
D3: White; LED_0603_1608Metric_White
D4: Blue; LED_0603_1608Metric_Blue
D5: Yellow; LED_0603_1608Metric_Yellow
D6: Red; LED_0603_1608Metric_Red
FID1, FID2, FID3, FID4: Fiducial_0.5mm; Fiducial_0.5mm_Mask1mm
G1: SparkFun_Logo
G3: OSHW_Logo; Creative_Commons_License
J1: Raspberry_Pi_2x20_SMD_Passthrough; Raspberry_Pi_Shield_Top_Entry_No_Mounting_Holes
J2, J4: Conn_02x10; 2x10_2.0mm_Male_Pins_Vertical_SMD_Pegs
J3: U.FL
J5: microSD_Friction; microSD_Friction_Fit_Common
J6: USB_C_Receptacle; USB-C_16
J7: SMA_Edge
J8: Qwiic_Vertical; JST_SMD_1.0mm-4_Vertical_Black
J9: Conn_01x05; 1x05
JP1: Jumper_3_NC-2_Trace
JP2: Jumper_3_NO
JP3, JP4, JP5, JP6, JP7, JP8, JP9, JP10, JP11, JP12, JP13, JP14, JP15, JP22, JP23, JP24, JP25: Jumper_2_NC_Trace
PPS1.1: Jumper_2_NC_Trace
PVT.1: Jumper_2_NC_Trace
PWR.1: Jumper_2_NC_Trace
R1, R2, R4, R5: 3.9k; R_0603_1608Metric
R3, R11: 1k; R_0603_1608Metric
R6, R7, R8: 10k; R_0603_1608Metric
R9, R10: 5.1k; R_0603_1608Metric
R12, R13: 2.2k; R_0603_1608Metric
R14: 4.7k; R_0603_1608Metric
RTK.1: Jumper_2_NC_Trace
ST1, ST2, ST3, ST4: Standoff
ST5, ST6, ST7, ST8: Standoff; Standoff_Hole-2.75mm_Clearance-1.625mm
TP1, TP2, TP3, TP4, TP5, TP6, TP7, TP8, TP9, TP10, TP11, TP12, TP13, TP14, TP15, TP16, TP17, TP18, TP19, TP20, TP21, TP22, TP23, TP24, TP25, TP26, TP27, TP28, TP29, TP30, TP31: 1.25mm; TestPoint-1.25mm
TR1: RFCMF1220100M4T
U1: CAT24C512WI-GT3; SO-8; not fitted
U2: AP7361C-3.3V; UDFN-8
U3: RT9080-3.3; SOT23-5

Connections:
3.3V: C1.1, C3.2, C6.1, C7.1, C8.1, C9.2, C10.1, C11.2, C12.1, C13.1, C14.2, C15.1, J2.1, J2.20, J4.1, J4.20, J5.4 (VDD), J8.2, J9.2, JP1.2 (B), JP2.2 (B), PWR.1.2 (B), R3.2, R6.2, R7.2, R8.2, U1.8 (VCC), U2.1 (VOUT)
5V: C2.2, C4.2, J1.2 (5V), J1.4 (5V), TP22.1, U2.8 (VIN), U3.1 (VIN), U3.3 (EN)
CTS2: J4.7, JP11.2 (B)
CTS3: J4.4, JP7.2 (B)
D+: J2.17, TP25.1, TR1.4
D-: J2.15, TP24.1, TR1.2
EVENTA: J2.6, JP24.1 (A)
EVENTB: J2.8, JP25.1 (A)
GND: C1.2, C2.1, C3.1, C4.1, C5.1, C6.2, C7.2, C8.2, C9.1, C10.2, C11.1, C12.2, C13.2, C14.1, C15.2, D1.2 (GND), D2.2 (A), D3.1 (K), D4.1 (K), D5.1 (K), D6.1 (K), J1.6 (GND), J1.9 (GND), J1.14 (GND), J1.20 (GND), J1.25 (GND), J1.30 (GND), J1.34 (GND), J1.39 (GND), J2.3, J2.18, J3.2 (Ext), J4.3, J4.18, J5.6 (VSS), J5.10 (SHIELD), J6.GND, J7.2 (Ext), J8.1, J9.1, JP3.1 (A), R9.1, R10.1, TP31.1, U1.1 (A0), U1.2 (A1), U1.3 (A2), U1.4 (GND), U2.4 (GND), U2.9 (EP), U3.2 (GND)
GPIO26: J1.37 (GPIO26), J9.4
ID_SC: J1.28 (ID_SC/GPIO1), R1.1, TP2.1, U1.6 (SCL)
ID_SD: J1.27 (ID_SD/GPIO0), R2.1, TP1.1, U1.5 (SDA)
unnamed: D1.1 (I/O1), J6.A6 (D+), J6.B6 (D+), TR1.3
unnamed: D1.3 (I/O2), J6.A7 (D-), J6.B7 (D-), TR1.1
unnamed: D3.2 (A), R11.1
unnamed: D4.2 (A), R12.1
unnamed: D5.2 (A), R13.1
unnamed: D6.2 (A), R14.2
unnamed: J1.7 (GCLK0/GPIO4), JP4.1 (A), TP5.1
unnamed: J1.29 (GCLK1/GPIO5), JP5.1 (A), TP6.1
unnamed: J1.31 (GCLK2/GPIO6), JP6.1 (A), TP7.1
unnamed: J1.8 (GPIO14/TXD), JP14.2 (B), TP15.1
unnamed: J1.10 (GPIO15/RXD), JP15.2 (B), TP16.1
unnamed: J1.15 (GPIO22), JP22.2 (B), TP17.1
unnamed: J1.16 (GPIO23), JP23.2 (B), TP18.1
unnamed: J1.18 (GPIO24), JP24.2 (B), TP19.1
unnamed: J1.22 (GPIO25), JP25.2 (B), TP20.1
unnamed: J1.19 (PICO0/GPIO10), JP10.1 (A), TP11.1
unnamed: J1.21 (POCI0/GPIO9), JP9.1 (A), TP10.1
unnamed: J1.32 (PWM0/GPIO12), JP12.1 (A), TP13.1
unnamed: J1.33 (PWM1/GPIO13), JP13.1 (A), TP14.1
unnamed: J1.23 (SCLK0/GPIO11), JP11.1 (A), TP12.1
unnamed: J1.24 (~CE0/GPIO8), JP8.1 (A), TP9.1
unnamed: J1.26 (~CE1/GPIO7), JP7.1 (A), TP8.1
unnamed: J3.1 (In), J7.1 (In)
unnamed: J6.A5 (CC1), R9.2
unnamed: J6.B5 (CC2), R10.2
unnamed: J6.S (SHIELD), JP3.2 (B)
unnamed: JP1.1 (A), R5.2
unnamed: JP1.3 (C), R4.2
unnamed: JP2.1 (A), R1.2
unnamed: JP2.3 (C), R2.2
unnamed: PPS1.1.2 (B), R13.2
unnamed: PVT.1.2 (B), R12.2
unnamed: PWR.1.1 (A), R14.1
unnamed: R11.2, RTK.1.2 (B)
PPS1: J2.2, JP22.1 (A), PPS1.1.1 (A)
PPS2: J2.4, JP23.1 (A)
PVT_LED: J2.9, PVT.1.1 (A)
Pi_3V3: J1.1 (3V3), J1.17 (3V3), TP23.1, U2.5 (EN)
RTK_LED: J2.7, RTK.1.1 (A)
RTS2: J4.9, JP10.2 (B)
RTS3: J4.5, JP6.2 (B)
RXD1: J4.19, JP14.1 (A)
RXD2: J4.12, JP8.2 (B)
RXD3: J4.8, JP4.2 (B)
RXD4: J4.13, JP12.2 (B)
SCL: J1.5 (SCL/GPIO3), J2.13, J8.4, R5.1, TP4.1
SDA: J1.3 (SDA/GPIO2), J2.11, J8.3, R4.1, TP3.1
SD_CLK: D2.3 (K2), J2.12, J5.5 (CLK/SCK), TP29.1
SD_CMD: D2.4 (K3), J2.10, J5.3 (CMD/SDI), R7.1, TP30.1
SD_DAT0: D2.1 (K1), J2.14, J5.7 (DAT0/SDO), R8.1, TP28.1
SD_DAT3: D2.5 (K4), J2.16, J5.2 (DAT3/~CS), R6.1, TP27.1
TXD1: J4.15, JP15.1 (A)
TXD2: J4.10, JP9.2 (B)
TXD3: J4.6, JP5.2 (B)
TXD4: J4.11, JP13.2 (B)
VBACKUP: C5.2, J2.5, TP21.1, U3.5 (VOUT)
VUSB: D1.5 (VCC), J2.19, J6.VBUS, TP26.1
WP: J9.3, R3.1, U1.7 (WP)
~RST: J4.16, J9.5

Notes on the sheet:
Er: 4.6
50Ohm
Raspberry Pi GPIO
Board thickness: 1.6mm
https://chemandy.com/calculators/coplanar-waveguide-with-ground-calculator.htm
Close jumpers to add pull-ups to bus
Open jumpers to remove pull-ups from bus
RF Trace Width: 13mil/0.33mm
Test Points
Polygon Isolation: 6mil/0.1524mm
microSD
Antenna
Open jumpers to disable LEDs
Dielectric thickness (layer 1 to 2): 0.2mm
LEDs
Voltage Regulation
USB Track Impedance: Differential Pair https://saturnpcb.com/saturn-pcb-toolkit/ Prepreg thickness: 8.3 mil (JLC7628). Er = 4.6 10.5 mil track with 9.5 mil gap (20 mil center to center) = 90 Ohms
Open jumpers to isolate GPIO pins
ID EEPROM
HAT+ Class "Standard" I2C Address 0b1010000
GNSS Plug-In Module
Microstrip Calculation:
I²C
USB-C
Copper Thickness (1oz): 1.4mil/0.035mm

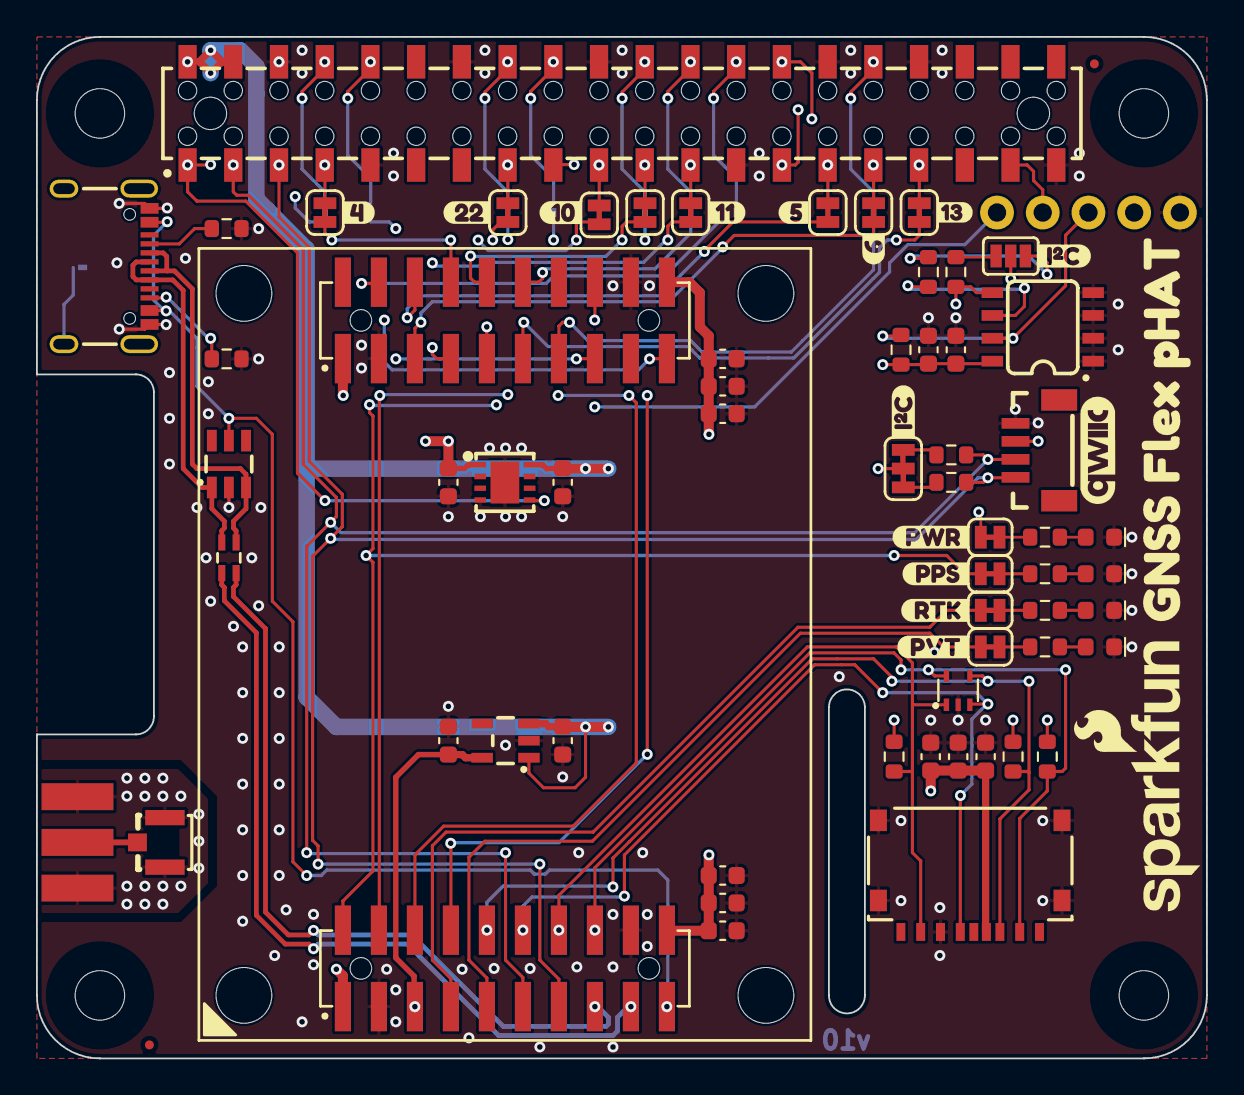
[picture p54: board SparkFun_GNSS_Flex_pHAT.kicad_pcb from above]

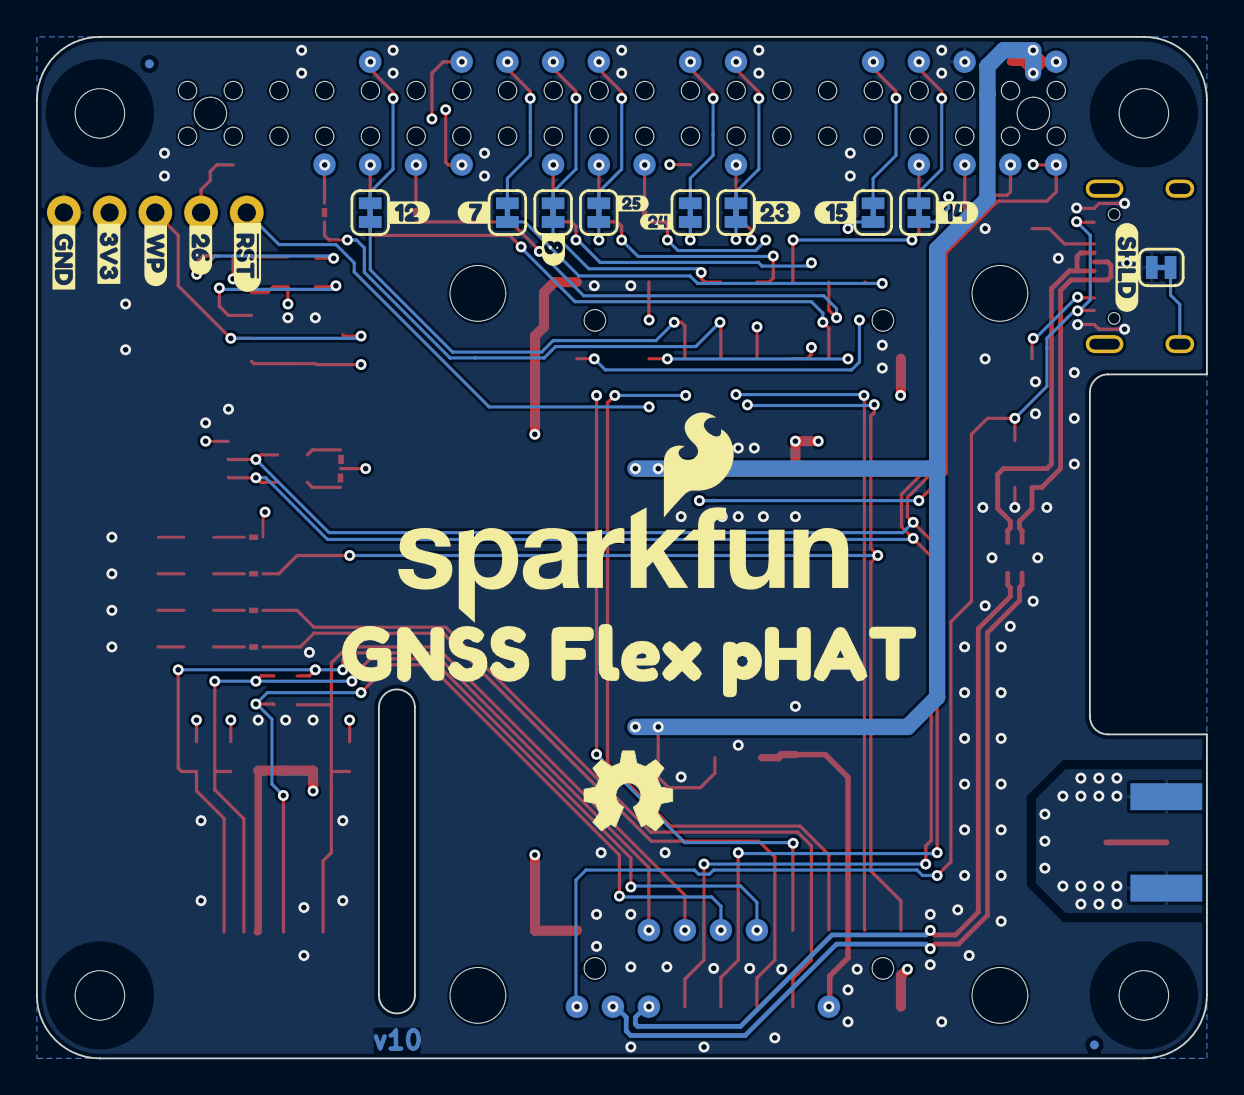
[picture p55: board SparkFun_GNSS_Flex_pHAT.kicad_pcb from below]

Board: 4 copper layers, 65.0 x 56.8 mm, 145 parts (58 on the bottom side), 71 nets.

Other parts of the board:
Ref**: Val**; OSHW_Logo_5mm
kibuzzard-67DC18B6: G***; kibuzzard-67DC18B6
kibuzzard-67DC1838: G***; kibuzzard-67DC1838
kibuzzard-678F8AD2: G***; kibuzzard-678F8AD2
kibuzzard-678F8D59: G***; kibuzzard-678F8D59
kibuzzard-678F8D86: G***; kibuzzard-678F8D86
kibuzzard-678F8DB2: G***; kibuzzard-678F8DB2
kibuzzard-678F8E11: G***; kibuzzard-678F8E11
kibuzzard-678F8E25: G***; kibuzzard-678F8E25
kibuzzard-678F8E41: G***; kibuzzard-678F8E41
kibuzzard-678F8E95: G***; kibuzzard-678F8E95
kibuzzard-678F8EB4: G***; kibuzzard-678F8EB4
kibuzzard-678F8ED3: G***; kibuzzard-678F8ED3
kibuzzard-678F8EED: G***; kibuzzard-678F8EED
kibuzzard-678F8F2B: G***; kibuzzard-678F8F2B
kibuzzard-678F8F11: G***; kibuzzard-678F8F11
kibuzzard-678F8F42: G***; kibuzzard-678F8F42
kibuzzard-678F92B8: G***; kibuzzard-678F92B8
kibuzzard-678F878F: G***; kibuzzard-678F878F
kibuzzard-678F893B, kibuzzard-678F893B#2: G***; kibuzzard-678F893B
kibuzzard-678F918F: G***; kibuzzard-678F918F
kibuzzard-678F8755: G***; kibuzzard-678F8755
kibuzzard-678F8777: G***; kibuzzard-678F8777
kibuzzard-67922E39: G***; kibuzzard-67922E39
kibuzzard-67922EA6: G***; kibuzzard-67922EA6
kibuzzard-67922FE7: G***; kibuzzard-67922FE7
kibuzzard-679237A8: G***; kibuzzard-679237A8
kibuzzard-679237B7: G***; kibuzzard-679237B7
kibuzzard-67923645: G***; kibuzzard-67923645

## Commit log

2025-01-16 Very WIP
    [SparkFun_GNSS_HAT+.kicad_pcb, SparkFun_GNSS_HAT+.kicad_sch]
2025-01-17 More WIP
    [SparkFun_GNSS_HAT+.kicad_pcb, SparkFun_GNSS_HAT+.kicad_sch]
2025-01-22 Change dimensions to mm
    [SparkFun_GNSS_HAT+.kicad_pcb]
2025-01-23 Change name to GNSS pHAT
    [SparkFun_GNSS_HAT+_panelized.GBL, SparkFun_GNSS_HAT+_panelized.GBO, SparkFun_GNSS_HAT+_panelized.GBP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]
2025-01-23 pHAT routed and panelized
    [SparkFun_GNSS_pHAT.kicad_pcb, SparkFun_GNSS_pHAT.kicad_sch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]
2025-01-23 Updates to match KiCad lib after #171
    [SparkFun_GNSS_pHAT.kicad_pcb, SparkFun_GNSS_pHAT.kicad_sch]
2025-01-27 Increase via size
    [SparkFun_GNSS_pHAT.kicad_pcb]
2025-01-29 pHAT updated after review
    [SparkFun_GNSS_pHAT.kicad_pcb, SparkFun_GNSS_pHAT.kicad_sch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]
2025-01-30 Update standoffs. Change panel to 2x2
    [SparkFun_GNSS_pHAT.kicad_pcb, SparkFun_GNSS_pHAT.kicad_sch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]
2025-01-31 Update RPi passthrough connector PROD_ID
    [SparkFun_GNSS_pHAT.kicad_pcb, SparkFun_GNSS_pHAT.kicad_sch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]
2025-01-31 Change I2C pull-ups to 3.9K RES-08701
    [SparkFun_GNSS_pHAT.kicad_pcb, SparkFun_GNSS_pHAT.kicad_sch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]
2025-03-20 v10 - update connectors and silk
    [SparkFun_GNSS_pHAT.kicad_pcb, SparkFun_GNSS_pHAT.kicad_sch]
2025-03-20 v10. Rename to Flex pHAT. Update 2x10 connectors and silk.
    No paste changes
    The only PnP changes are the 2x10 connector type. PnP coordinates are all the same.
    [SparkFun_GNSS_Flex_pHAT.kicad_pcb, SparkFun_GNSS_Flex_pHAT.kicad_sch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]
2025-05-20 Update README.md
    Fix merge errors
    Remove "print view" link
2025-05-20 Replace center tag
    Replace the use of `<center>` tag for deprecation, as described in issue: https://github.com/squidfunk/mkdocs-material/issues/8163
2025-05-20 Add UART highlight colors
2025-05-20 Add UART tips and how-to enable the additional ports
2025-05-21 Update mkdocs.yml
    Add repo and uri configuration
    - Edit button link is still wrong, but better than redirecting to incorrect repo
2025-05-22 Update kicad_files.zip
    Add project file
2025-08-20 Add LDO Datasheets
    Add datasheets for voltage regulators
2025-08-20 Add images
    - Template for board layout
    - Breakout pins (EEPROM - not used)
2025-08-20 Link U.FL Cable
    Add product link for 50mm U.FL cable
2025-09-12 Update KiCAD files
    Update the file path to the 3D model of the RF choke's footprint
    Remove ignored file type
    [SparkFun_GNSS_Flex_pHAT.kicad_pcb]
2025-09-15 Update hardware_assembly.md
    Update instructions for connecting an external antenna
2025-09-15 Update software_overview.md
    Adds instructions for enabling the I2C interface
    Add example for configuring the UART interface on a Pi 5
2025-09-18 Update docs
    Fix grammar
    Fix link
    Fix table
    Adds instructions for connecting Qwiic devices
2025-09-18 Add GNSS Flex Breakout
    Adds product link to GNSS Flex Breakout board
    Adds new release version updates
2025-09-18 Add links for Flex board pages
    Links to main carrier board and modules pages
2025-09-18 Update hardware_assembly.md
    Small formatting change to match GNSS Flex breakout board
2025-10-10 Update 3D model
    Refactored the 3D model for all the GNSS Flex boards to a new standardization
    Eliminated the manual adjustments required for any new 3D models
    - Modified the old models, so any new models can be adopted without any changes after they have been optimized

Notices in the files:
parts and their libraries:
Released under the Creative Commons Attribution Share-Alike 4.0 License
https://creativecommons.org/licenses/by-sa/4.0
